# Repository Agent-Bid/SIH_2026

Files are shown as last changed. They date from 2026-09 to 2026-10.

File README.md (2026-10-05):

# Adaptive sonar waveform generator (Tang Nano 9K + ESP32-S3)

An ESP32-S3 takes the water conditions (simulated for now), runs an acoustics model and three
small neural networks, and picks a sonar waveform for every ping, 6 a second: the frequency
band and pulse length, the amplitude, and the modulation (BPSK, LFM or geometric, from how fast
the target moves). It sends the choice over SPI to a Tang Nano 9K FPGA, which generates the
pulses sample by sample at 50.14 MHz for an 8-bit DAC, each with a Hann window.

A PC can stand in for the ESP32 over the Tang Nano's USB UART, and can capture pulses back
from the FPGA (one, or every ping) to check them sample for sample against a Python golden
model.

**Technical documentation** (problem, scientific basis, design, results, limitations, references):
[`docs/Adaptive_Sonar_Technical_Documentation.pdf`](docs/Adaptive_Sonar_Technical_Documentation.pdf)
(also as `.docx`).

**Full project details** (design, packet format, pins, toolchain quirks, status, open items):
[`AGENTS.md`](AGENTS.md). ESP32 firmware and its physics write-up: `MCU /SIH/`.

## Use it

**Demo**: power the ESP32 (it starts pinging on its own), plug the Tang Nano into the PC, then

```
python3 host/demo.py                  # one second: 6 pings on one graph, with the conditions behind each
```

It streams 6 consecutive pings from the FPGA, checks each against the golden model, and plots
them at their real times over one second (grey = baseline, no output), with a table of the
water conditions, the waveform chosen, what the neural networks picked, and the check result
(`sim/out/demo.png`). The ESP32's USB log is used if it is connected; otherwise the conditions
are recomputed from each packet's number (`host/water_sim.py`).

**Other tools**:

```
tn9k load                                                        # build + load the FPGA

python3 host/wavegen.py chirp --fc 325e3 --bw 350e3 --capture    # LFM 150 -> 500 kHz
python3 host/wavegen.py geo   --fc 325e3 --bw 350e3 --capture    # geometric 150 -> 500 kHz
python3 host/wavegen.py bpsk  --fc 300e3 --capture               # Barker-13 at 300 kHz
python3 host/wavegen.py tone  --fc 200e3 --amp 0.75 --capture

python3 host/capture.py --request                                # capture what is playing now
```

- `--capture` asks the board for the next pulse, checks it against the golden model and saves
  a plot in `sim/out/board_capture_<kind>.png` (waveform + spectrogram with the expected sweep).
  Long pulses are captured whole by keeping one sample in 4, 16 or 64.
- `wavegen.py` pulses are 13,000 clocks (259 µs); sweeps go up from `fc - bw/2` to
  `fc + bw/2`; BPSK uses Barker-13 at 1,000 clocks per chip. Other options: `--amp 0..1`,
  `--period <clocks>`, `--port`, `--dry-run`.
- With the ESP32 connected, its packets (one per ping) replace the PC's settings; use
  `capture.py --request` to see what it chose. The ESP32's serial console
  (`python3 host/esp_console.py`): `A` automatic (simulated conditions, the default),
  `W` type the inputs, `M geo|bpsk|lfm|cw|auto` force a modulation, `R 450` the target range.
- The PC talks to the FPGA at 3 Mbaud (`/dev/ttyUSB1`).
- **The DAC output without a scope**: wire pin 40 → 1 kΩ + 100 pF → 10 kΩ + 10 pF → ESP32
  GPIO 1, then `python3 host/dac_view.py --amp 1`. The ESP32 records the filtered voltage while
  the FPGA plays a slow-motion copy of the current ping, and the plot lays it over the FPGA's own
  samples (`sim/out/dac_view.png`). `python3 host/dac_sequence.py` does it for one second of
  pings (6 decisions, each recorded 4× and averaged) on one graph (`sim/out/dac_sequence.png`).
- **The DAC output at full speed**: the filter is now RC (1 kΩ + 100 pF) → OPA340 Sallen-Key
  (10 kΩ, 1 kΩ, 100 pF feedback, 20 pF) on the LASC board's channel 2 (output J6 pin 7). A
  BlackPill (`blackpill/`, flash with `pio run -t upload` in DFU mode) records it at 2.4 MS/s on
  PA1, triggered by pin 41 on PB0. `python3 host/real_speed.py` records 6 consecutive pings, pairs
  each with the FPGA's header for that pulse and plots them unslowed (`sim/out/real_speed.png`).
- **Filter design files**: `hardware/sallen_key_filter/` holds the KiCad schematic of the output
  filter (RC, OPA340 Sallen-Key, RC) and `ac_sweep.cir`, an ngspice AC sweep of it
  (`ngspice ac_sweep.cir`).
- On the board: **S1** steps through three presets (chirp, geometric, BPSK), **S2** captures
  the next pulse (listen with `python3 host/capture.py`).
- **Oscilloscope** (no DAC needed): pin 40 → 1 kΩ → probe point, 100 pF from the probe point
  to GND; trigger on pin 41 (high during each pulse). Without any parts, pin 34 shows a square
  wave at the waveform's frequency (sweep and BPSK phase jumps visible, window not).
- LEDs: 0 BPSK, 1 armed, 2 recording/sending, 3 blinks per good SPI packet, 4 pulse active,
  5 geometric.

## Test in simulation

```
sim/all        # 11 testbenches, ALL PASS
```

`sim/top_tb.v` simulates the whole board: settings over the UART, a pretend ESP32 on SPI
(including a packet with a broken CRC, which must be rejected), and three captures checked
by `host/capture.py`.

## Verified on the board

- 2026-09-29: with the 57-byte packet format, LFM chirp, geometric sweep, BPSK and a tone at
  half amplitude all matched the golden model on all 16,383 captured samples (settings sent
  from the PC over the UART).
- 2026-09-30: the full chain on the boards. The ESP32 (physics + neural network) sends its
  choice over SPI 10 times a second (0 bad packets), and the FPGA plays it bit-exact: an H-S
  chirp at 300 m, then an M-S geometric sweep after `R 600` and `M geo`. Packets are framed by
  the pause after each burst instead of CS (the CS wire does not work on these boards; see
  `AGENTS.md`).
- 2026-09-30: with the oscilloscope outputs added and `scale` split into two clocks (the
  single-clock multiply failed on the chip), ESP32 and PC captures were all bit-exact.
- 2026-09-30: the demo: simulated conditions on the ESP32, 6 pings a second, each a new
  decision; 6 consecutive pings streamed from the FPGA, all bit-exact. This build is in the
  FPGA's flash.
- 2026-10-04: the sigma-delta DAC's filtered output, recorded by the ESP32's ADC in slow motion,
  matches the FPGA's samples (correlation 0.998 at full amplitude; BPSK phase flips visible).

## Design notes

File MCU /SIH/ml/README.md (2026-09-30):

# Waveform-choice model

The ESP32 chooses the waveform with three small neural networks, compiled into the firmware
as `../ml_model.h` (30 KB of weights):

- **profile network** 6 → 48 → 48 → 6 (ReLU): one score for each profile the rule ever picks
  (X-S, H-S, M-S, L-S, L-M, L-L); the highest wins.
- **amplitude network** 12 → 48 → 48 → 1: the 6 inputs plus the chosen profile (one-hot) →
  log(amplitude that just closes the link), plus a small safety margin.
- **modulation network** 16 → 32 → 32 → 3: temperature, salinity, depth, log10(speed + 0.01)
  and the profile (one-hot of 12) → LFM, geometric or BPSK: the Doppler rule in
  `sonar_config.h` section 4c (drift over the pulse ≤ 0.25 cycles → BPSK, ≤ 1 → LFM, else
  geometric). Trained on 200,000 random (conditions, speed, profile) triples.

**Inputs**: temperature (°C), salinity (ppt), depth (m), turbidity (NTU), battery (%), target
range (m); the range is fed as log10(range), and every input is standardised.

**What it learns**: the physics' choice under the detail-vs-energy rule (`sonar_config.h`
section 4b): the finest profile that closes the link using at most 4 × the energy of the
cheapest working profile, or 1 % of the ping's energy budget, whichever is more; and the
amplitude that just closes the link for a profile. The physics still checks every answer:
the profile is kept when it passes the same test (`FLAG_ML_USED`), else replaced
(`FLAG_ML_OVERRIDDEN`); the amplitude is raised if it is too low (`FLAG_ML_AMP_RAISED`).
Set `USE_ML_MODEL 0` in `adaptive_sonar.ino` for physics only.

**Results** (`REPORT.md`): the profile agrees with the physics on about 99.2–99.4 % of
scenarios and 0.5 % of picks are overridden; the amplitude is within 1.8 % (median) of what is
needed and costs 1.6–3.4 % more energy than the minimum; the modulation agrees on 99.7 % (0.2 %
overridden, all at a threshold). XGBoost and a decision tree are
trained on the same data for comparison: the boundaries are smooth curves, which the network
fits with far fewer parameters. The labels come from the physics, so the model reproduces the
physics; it cannot be more accurate than it.

**Retrain** (about 5 minutes on a laptop CPU; no GPU needed):
```
python3 -m venv ml/.venv && ml/.venv/bin/pip install -r ml/requirements.txt
ml/.venv/bin/python ml/train.py          # writes ../ml_model.h, test_vectors.csv, REPORT.md
```
Retrain after any change to `sonar_config.h` that affects the choice (profiles, power,
thresholds, the detail-vs-energy knobs, sensor ranges), then run the firmware tests:
`tools/test_core.cpp` checks that the C networks give the Python models' profile and amplitude
on `test_vectors.csv`, and modulation on `test_vectors_mod.csv`.

**Later, real data**: the model only beats the physics once it learns from measurements.
Log the inputs, the chosen profile and the measured result of each ping (for example the
received level), and train on that instead of the physics labels (`make_set()` in `train.py`).

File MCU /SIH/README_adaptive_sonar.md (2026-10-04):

# Adaptive Sonar Engine — ESP32-S3 + FreeRTOS (100–500 kHz)

This is the final firmware package for the "ESP32 decides, FPGA transmits" design.
This file explains **what the code does in simple words**, **every assumption and correction I made**, and **what the team still has to decide**.

---

## 1. The idea in 60 seconds

The sonar sits in water. The water changes (temperature, salinity, depth, cloudiness) and the battery drains.
Sound at 500 kHz gives very sharp detail but dies quickly in water; sound at 100 kHz travels far but is less sharp.

So the ESP32 does one job for every ping, 6 times a second:

1. **Read 7 inputs**: temperature, salinity, depth, turbidity, battery, target range and the
   target's relative speed. For now they come from a built-in simulation of changing water
   conditions (`water_sim.h`, below); they can also be typed on the serial console or read
   from potentiometers.
2. **Work out the water**: how fast sound travels, how much of it is absorbed at each frequency, how much the murky water and distance weaken it, how noisy the sea is.
3. **Choose a waveform "profile"**: the finest detail that still works with enough signal margin, **unless that costs much more energy** than the cheapest profile that works (the detail-vs-energy rule, section 4).
4. **Set the power just high enough** (so it doesn't waste battery).
5. **Choose the modulation from the motion**: motion shifts every frequency (Doppler), so over
   one pulse the phase drifts fd·T cycles (fd = speed / c × fc). BPSK (Barker-13) while the
   drift is at most 0.25 cycles (cleanest when still), LFM up to 1, geometric sweep beyond
   (tolerates the most motion). Thresholds in `sonar_config.h` section 4c.
6. **Send the choice to the FPGA over SPI.** The FPGA makes the actual pulse.

**The ML model picks the profile, its amplitude and the modulation; physics checks all three.** Three small neural networks (trained on the physics' own decisions, `ml/`) propose them. The physics keeps the profile when it closes the link within the energy allowance (otherwise it chooses itself), raises the amplitude if it is too low, and replaces a modulation that cannot take the Doppler drift. With `USE_ML_MODEL 0` the physics alone decides.

**Simulated water conditions** (`water_sim.h`, the default at power-on; `A` on the serial
console returns to it): a vehicle dives and climbs between 20 and 350 m through a thermocline
(22 → 5 °C) and a halocline, turbidity drifts (plumes, and a muddy layer near the bottom), the
battery drains (and recharges at 15 %), and the sonar tracks three contacts, one per ping in
turn: A near (15–180 m) and lively, B mid-range (250–600 m) and nearly still, C far (450–1000
m) and moving. Ranges and speeds follow smooth random motions, every reading has a little
noise, and mission time runs 10× faster than real time. It is deterministic from its seed.

---

## 2. Files

| File | What it is | Who edits it |
|---|---|---|
| `adaptive_sonar/sonar_config.h` | **Every tunable number** + the profile table | The team (this is the control panel) |
| `adaptive_sonar/sonar_core.h` | Physics, decision logic, FPGA packet. No Arduino code inside, so it can be tested on a PC | Only if the physics changes |
| `adaptive_sonar/adaptive_sonar.ino` | Pins, ADC, FreeRTOS tasks, SPI, serial console | Firmware owner |
| `adaptive_sonar/water_sim.h` | Simulated water conditions (the default input) | Anyone |
| `tools/physics_reference.py` | Python twin of the physics. Reads the **same** `sonar_config.h`; generates ML datasets | ML owner |
| `adaptive_sonar/ml_model.h` | The ML model as C (generated by `ml/train.py`, do not edit) | Regenerate |
| `ml/train.py`, `ml/README.md`, `ml/REPORT.md` | Training: data from the physics twin, model comparison, C export, results | ML owner |
| `tools/test_core.cpp`, `run_tests.sh` | PC tests (see section 9) | Anyone |

Arduino needs the sketch folder name to match the `.ino`, so keep the folder named `adaptive_sonar`.

---

## 3. The 12 profiles

A profile = one ready-made chirp: centre frequency, sweep width (bandwidth), pulse length.
They are ordered **best detail first**; the code takes the first one that works.
(All are linear-FM chirps. Each keeps its full band inside 100–500 kHz.)

| ID | Name | Band | Centre | Bandwidth | Pulse | Range resolution* |
|---|---|---|---|---|---|---|
| 0 / 1 / 2 | X-S / X-M / X-L | 380–500 kHz | 440 kHz | 120 kHz | 1 / 5 / 20 ms | ~0.6 cm |
| 3 / 4 / 5 | H-S / H-M / H-L | 270–330 kHz | 300 kHz | 60 kHz | 1 / 5 / 20 ms | ~1.3 cm |
| 6 / 7 / 8 | M-S / M-M / M-L | 180–220 kHz | 200 kHz | 40 kHz | 1 / 5 / 20 ms | ~1.9 cm |
| 9 / 10 / 11 | L-S / L-M / L-L | 100–140 kHz | 120 kHz | 40 kHz | 1 / 5 / 20 ms | ~1.9 cm |

\*resolution = c / (2 × bandwidth). ID 11 (L-L) is the "best effort" fallback: lowest frequency, longest pulse.

**Why these letters?** Frequency tier (X, H, M, L) controls detail vs reach. Pulse length (S, M, L) controls how much energy goes out per ping.

### The one physics fact that shapes everything
After pulse compression, the signal-to-noise ratio depends on **pulse energy** (power × time), **not on bandwidth**.
So:
- **Bandwidth** buys sharper resolution and costs nothing in SNR.
- **Longer pulse or more power** buys SNR.
- **Higher frequency** buys detail but loses signal faster (absorption grows steeply).

That's why within a frequency tier the code prefers the **shortest** pulse that fits (fast updates, small blind zone) and only goes to longer pulses when the peak-power limit forces it.

A second fact follows from the same physics: **a lower frequency always needs less energy** (water absorbs less, thermal noise is lower). With the detail-vs-energy rule, the longer pulses of the X, H and M tiers are therefore never chosen: they are only needed when the short pulse would exceed the 20 W peak power, which happens at long range, where a lower tier is always much cheaper. In practice the choice is among X-S, H-S, M-S, L-S, L-M and L-L.

---

## 4. How the decision works, step by step

For each profile, best detail first:

1. **Sound speed** from Mackenzie (temperature, salinity, depth).
2. **Absorption** at the profile's centre frequency from Francois-Garrison (temperature, salinity, depth, pH).
3. **Turbidity loss** (extra attenuation from suspended particles).
4. **Spreading loss** = 20·log10(range).
5. **Total transmission loss** = spreading + (absorption + turbidity) × distance.
6. **Noise** = thermal noise + wind noise + receiver noise figure.
7. **Power needed** so that output SNR ≥ 12 dB threshold + 3 dB margin.
8. **Check limits**: needed power ≤ transmitter maximum, and needed energy ≤ what the battery allows per ping, and the chirp fits in the band.
9. **Energy per ping** of every profile that fits: power × pulse length (just enough power, never below 5 % amplitude).
10. **Energy allowance** = the larger of `DETAIL_ENERGY_FACTOR` (4) × the cheapest profile's energy, and `DETAIL_FREE_ENERGY_FRAC` (1 %) × this ping's energy budget. Extra detail is worth up to 4× the minimum energy; energy below 1 % of the budget is too small to be worth saving. The budget shrinks with the battery, so a low battery leans towards saving energy.
11. **Take the finest profile that fits within the allowance.**
12. If nothing fits → last profile at maximum allowed power, flagged `BEST_EFFORT`.

**Anti flip-flop:** to move *up* to a finer profile than the current one, the link needs 2 dB extra margin (which also raises the energy it is charged with). Moving down happens immediately. The same check applies to the ML's pick, so a jittery sensor at a profile boundary cannot make the waveform flip back and forth.

**Tuning:** `DETAIL_ENERGY_FACTOR 1` always takes the cheapest profile (nearly always L-S: the worst detail); a very large value takes the finest profile that works (the older rule).

### Example results (from the Python twin; same numbers as the firmware)

Salinity 35 ppt and depth 50 m in every row.

| Scenario | Old rule (finest that works) | Chosen now | Amplitude | Energy per ping | Old rule's energy | Link |
|---|---|---|---|---|---|---|
| Clear, 10 °C, 300 m, full battery | X-S | **X-S** (440 kHz, 1 ms) | 0.33 | 2.24 mJ | 2.24 mJ | OK |
| Same water, 600 m | H-M | **M-S** (200 kHz, 1 ms) | 0.33 | 2.23 mJ | 68.0 mJ | OK |
| Same water, 600 m, 15 % battery | M-S | **L-S** (120 kHz, 1 ms) | 0.08 | 0.14 mJ | 2.23 mJ | OK |
| Same water, 1000 m | L-S | **L-S** (120 kHz, 1 ms) | 0.84 | 14.2 mJ | 14.2 mJ | OK |
| Warm 25 °C, turbid 80 NTU, 300 m | H-M | **M-S** (200 kHz, 1 ms) | 0.16 | 0.51 mJ | 24.9 mJ | OK |
| Turbid 80 NTU, 15 % battery, 800 m | L-S | **L-S** (120 kHz, 1 ms) | 0.94 | 17.8 mJ | 17.8 mJ | OK |
| Extreme: 2 km, 100 NTU, 10 % battery | L-L | **L-L** (120 kHz, 20 ms) | 0.32 | 40.0 mJ | – | best effort |

Battery only changes the answer when the link is tight (long range), because at short range the energy needed is tiny compared to the budget.

---

## 5. RTOS structure (why the CPU won't stall)

Four tasks, connected by "latest value" queues (length 1, overwrite; plus a short log queue for the PING lines). Nobody waits on anybody, and a slow task can never build a backlog.

```
 core 1                                             core 0
 ┌─────────────┐  latest sample  ┌───────────────┐  latest packet  ┌────────────┐
 │ sensorTask  │ ──────────────▶ │ decisionTask  │ ──────────────▶ │  spiTask   │──▶ FPGA
 │ 50 Hz, prio2│                 │ 6 Hz, prio 3  │                 │50 Hz, prio4│
 │ ADC+filter  │                 │ sim + ML +    │                 └────────────┘
 └─────────────┘                 │ physics       │                 ┌─────────────┐
                                 └──────┬────────┘   telemetry     │ consoleTask │ prio 1
                                        └────────────────────────▶ │ Serial+cmds │
                                                                   └─────────────┘
```

- **sensorTask**: reads 5 pots (16-sample average each) and smooths them, or passes on the typed inputs; publishes the latest. (Not used in automatic mode.)
- **decisionTask**: one decision per ping, 6 a second (exactly on average). In automatic mode it steps the simulation first. Runs the networks and the physics; keeps the anti flip-flop memory per contact. It never touches SPI or Serial, so it can't be blocked by them.
- **spiTask**: highest priority, every 20 ms, sends the latest packet, so a new decision reaches the FPGA well before its next ping.
- **consoleTask**: lowest priority. Serial commands, the PING lines, the reports.
- If sensor data is older than 500 ms, decisions are skipped and the last good packet keeps going.
- The Arduino `loop()` does nothing; all work is in tasks.

**Serial console** (115200; open it with DTR and RTS off, e.g. `host/esp_console.py` in the FPGA project):
- `A`: automatic, simulated conditions (the default). One line per ping:
  `PING seq=… contact=… T=… S=… D=… turb=… bat=… R=… v=… profile=… mod=… amp=… ml_profile=… ml_mod=… ml_amp=… flags=… doppler=…`
- `W`: type the seven inputs one by one (Enter keeps a value, `q` cancels), then a full report: what each network picked and what the physics did with it, the result, and the values sent to the FPGA. `I T S D turb bat R v`: the same on one line, ending with a `DECISION` line for programs.
- `R 450`: target range. `M lfm | geo | bpsk | cw | auto`: force a modulation (`auto` = from the motion). `P`: potentiometers. `L`: status line. `?`: help.
- `C [amp]`: DAC view. Sends the FPGA a slow-motion copy of the current ping (frequencies ÷ up to 100, so the ADC can follow), records the DAC filter's output on GPIO 1 with the ADC (up to 80 kS/s), and prints it (`CAP` header, `D` lines of hex millivolts, `END`) for `host/dac_view.py` in the FPGA project. `S [n] [r]`: the same for the next n decisions (default 6), each recorded r times (default 4), with a `COND` line of conditions before each; for `host/dac_sequence.py`.
- The console writes in small pieces and waits for each to leave: the USB-Serial/JTAG driver loses text that is queued faster than the host reads it, and `Serial.flush()` can discard it.

---

## 6. Packet to the FPGA (57 bytes, little-endian, SPI mode 0)

Version 3. The MCU sends every waveform number **in the FPGA's own units**, so the FPGA never
divides. FTW ("frequency tuning word") = f × 2³² / F_CLK, with F_CLK = 27 MHz × 13/7 =
50.142857 MHz (`FPGA_CLK_HZ` in `sonar_config.h`). The FPGA reads byte 5 and bytes 28–55.

| Bytes | Field | Meaning |
|---|---|---|
| 0 | `sync` | always `0xA5` |
| 1 | `version` | 3 |
| 2–3 | `seq` | counter, increments on each new decision |
| 4 | `profileId` | 0–11 |
| 5 | `modulation` | **FPGA:** 0 = CW, 1 = LFM chirp, 2 = geometric sweep (both up, fc−bw/2 → fc+bw/2), 3 = BPSK Barker-13 at fc |
| 6 | `spreadingFactor` | round(log2(bw × T)) for the sweeps |
| 7 | `flags` | bit0 link OK, bit1 low battery, bit2 input clamped, bit3 ML used, bit4 best effort, bit5 ML overridden, bit6 ML amplitude raised |
| 8–11 | `centerFreqHz` | informational |
| 12–15 | `bandwidthHz` | informational |
| 16–19 | `pulseUs` | informational: pulse duration in µs |
| 20–21 | `amplitude` | informational: 0–65535 = 0–100 % drive |
| 22–23 | `txPowerMilliW` | electrical, informational |
| 24–27 | `propDelayUs` | one-way delay to target range |
| 28–31 | `lenClk` | **FPGA:** pulse length in FPGA clocks (max 2²⁴−1 ≈ 335 ms; BPSK: 13 whole chips) |
| 32–35 | `ftwStart` | **FPGA:** start frequency as an FTW (fc for CW/BPSK, fc − bw/2 for the sweeps) |
| 36–39 | `ftwStep` | **FPGA:** LFM: FTW change per clock × 2¹⁶ (signed). Geometric: (ratio − 1) × 2³², applied every 32 clocks, ratio = (f_end/f_start)^(1/(lenClk/32)). CW/BPSK: 0 |
| 40–43 | `winStep` | **FPGA:** 2³² / lenClk (the Hann window makes one lap per pulse) |
| 44–45 | `ampQ12` | **FPGA:** amplitude, 4096 = 1.0 |
| 46–47 | `code` | **FPGA:** BPSK phase code, chip i = bit i, 1 = flip (Barker-13 = `0x0A60`); else 0 |
| 48–51 | `chipLen` | **FPGA:** BPSK clocks per chip; else 0 |
| 52–55 | `periodClk` | **FPGA:** clocks from one pulse start to the next: `PING_PERIOD_MIN_S` (0.1 s), or pulse + round trip in echo mode |
| 56 | `crc8` | CRC-8 (poly 0x07, init 0) over bytes 0–55 |

The 16 fractional bits of the LFM step matter: a 20 ms, 40 kHz chirp needs a step of 3.416 FTW
per clock, and a whole-number step would sweep 12 % too little. `validateProfiles()` checks at
boot that every profile fits these fields with every modulation.

The FPGA owner must confirm the SPI mode, clock, byte order and whether they want CRC-checked packets (see section 8).

---

## 7. Assumptions and corrections

### 7a. Corrections (things in earlier versions that would not work, now fixed)

| # | What was wrong | What it is now | Why |
|---|---|---|---|
| 1 | **Thorp absorption** was in the earlier code and the team doc | **Francois-Garrison (1982)** | Thorp is a low-frequency fit. Francois-Garrison is published for 200 Hz–1 MHz, so it covers 100–500 kHz, and it uses temperature, salinity, depth and pH, which your doc says absorption should depend on. Thorp ignores temperature, salinity and depth. Example (35 ppt, surface): at 300 kHz Thorp says 67 dB/km, Francois-Garrison says 66 dB/km at 5 °C but 137 dB/km at 30 °C; at 500 kHz Thorp says 112 dB/km, Francois-Garrison says 129 (5 °C) to 199 (30 °C). Using Thorp would badly under-estimate loss in warm water. |
| 2 | Some public Francois-Garrison copies have a **digit typo** (`4.397e-4` instead of `4.937e-4` in the cold-water pure-water term) | Correct `4.937e-4` used | Checked three ways: matches the original paper's form, the two branches of the formula join continuously at 20 °C only with 4.937 (a unit test guards this), and every other term matches an independent public implementation to 6 digits. |
| 3 | Frequency band was 8–30 kHz (my first version) and 90–100 kHz (ML dataset) | **100–500 kHz** | Team requirement. |
| 4 | Simplified sound-speed formula in `predict_profile.py` | Full **Mackenzie** equation | Matches what the dataset was built with; check value 1550.744 m/s at 25 °C, 35 ppt, 1000 m is tested. |
| 5 | Made-up scattering, noise and source-level formulas in my previous code | Published models: thermal noise (Mellen: −15 + 20·log f), wind noise, source level `170.8 + 10·log(P) + DI` | Above ~100 kHz thermal noise dominates. |
| 6 | Earlier SNR ignored pulse compression | Output SNR includes it (`SNR = SL + 10·log T − loss − N0`) | Otherwise the chirp/spreading-factor idea has no effect on the decision. |
| 7 | Single loop with blocking ADC/SPI/Serial | FreeRTOS tasks + queues | Requested; also actually stops the stalls. |
| 8 | ML was the decision maker with nothing checking it | The ML proposes, physics verifies and overrides infeasible picks | Decided with you; the ML is required, physics keeps it safe. |
| 9 | Noise level and range were ML *inputs* but not on your sensor list | Noise is **calculated**; range is a **mission setting** (default 300 m, `R <m>` over Serial) | You only have the 5 sensors. |
| 10 | Boolean-only "feasible" flip-flopping on noisy pots | 2 dB hysteresis for switching up, EMA filtering of the pots | Real sensors are noisy. |
| 11 | XOR checksum, no sequence number | CRC-8 + sequence + version byte | FPGA can detect corruption and stale data. |

### 7b. Assumptions (nobody has confirmed these; all live in `sonar_config.h`)

| Assumption | Default | Confirm with |
|---|---|---|
| Sonar is a **one-way link** (same convention as the ML dataset). Set `ACTIVE_ECHO_MODE 1` for out-and-back echo sonar (doubles the loss, adds target strength −20 dB, and limits pulse length to the round-trip time) | one-way | Whole team |
| Transmitter: 20 W electrical peak, 50 % efficient, omnidirectional (DI = 0 dB) | 20 W / 0.5 / 0 dB | Hardware owner |
| Receiver noise figure | 6 dB | Hardware owner |
| Wind speed for wind noise (no sensor) | 5 m/s | Mission plan |
| pH (only matters below 10 kHz) | 8.0 | none needed |
| **Turbidity loss**: 0.15 dB/km per NTU at 100 kHz, growing linearly with frequency; 1 NTU ≈ 1 mg/L | see left | **Needs calibration.** Anchored to Richards, Heathershaw & Thorne (JASA 1996): about 3 dB extra over 100 m at 100 kHz for 0.2 kg/m³. NTU→concentration and the frequency scaling are site-specific. Set the coefficient to 0 to switch it off. |
| Required output SNR 12 dB (same as ML dataset) + 3 dB link margin for refraction, multipath and filter loss (refraction is not modelled) | 12 + 3 dB | Whole team |
| Spreading: spherical (20·log R) | 20 | Whole team |
| Energy per ping at 100 % battery: 0.4 J, shrinking linearly with SOC down to a 10 % floor | 0.4 J | Hardware owner |
| Absorption is evaluated at the chirp's centre frequency (not averaged across the band) | — | fine for a first version; the 3 dB margin covers most of it |
| Spreading Factor: I interpreted the doc's "SF" as `round(log2(bandwidth × pulse))` (LoRa-style: time-bandwidth = 2^SF) | — | Whoever wrote the doc |
| Pots span exactly the model's valid ranges: 2–30 °C, 25–40 ppt, 0–1000 m, 0–100 NTU, 0–100 % | see config | — |
| ADC full scale ≈ 3100 mV at 11 dB attenuation | 3100 mV | Measure with a multimeter |
| Target range default 300 m (10–2000 m allowed) | 300 m | Mission plan |
| Preference policy: **finest detail within the energy allowance** (4 × the minimum energy, or 1 % of the ping's budget) | `DETAIL_ENERGY_FACTOR` 4, `DETAIL_FREE_ENERGY_FRAC` 0.01 | Whole team (the two numbers set the trade-off) |

---

## 8. What will NOT work until the team decides (blockers)

1. **Transducer coverage.** One transducer rarely covers a 5:1 frequency span (100–500 kHz) with 40–120 kHz sweeps. The firmware assumes it can. If the hardware has separate transducers per band, the profile table and the FPGA switching logic must reflect that. Ask the hardware owner first.
2. **FPGA/DAC speed.** To synthesize up to 500 kHz the DAC/FPGA path must run well above 1 MS/s (Nyquist); realistically 2.5 MS/s or more. Confirm with the FPGA owner.
3. **SPI contract.** Agreed with the FPGA side: SPI mode 0, 2 MHz, packet v3 above, CRC-checked; no ready/ack line. **Verified on the boards (2026-09-30)**: 10 packets/s, none rejected, and the FPGA plays the chosen waveform bit-exact. The FPGA frames packets by the pause after each burst, because the CS wire (GPIO14 → pin 36) does not carry a clean signal on the current boards; the firmware still drives CS as usual.
4. **One-way or echo sonar?** This changes the loss maths (`ACTIVE_ECHO_MODE`). The ML dataset assumes one-way.
5. **Selection policy.** Decided: the detail-vs-energy rule (section 4). Still to tune: the two numbers in `sonar_config.h` section 4b (then retrain the ML).
6. **Turbidity attenuation** needs a real calibration (a turbidity sensor + a known-range acoustic test).
7. **Where the range comes from.** For now it is typed over Serial. If the mission needs it automatic, someone must supply an estimate.

---

## 9. What I verified, and what I could not

Verified on a PC:
- `sonar_core.h` compiles clean with strict warnings.
- Packet v3: the FPGA-unit fields for LFM, geometric and BPSK match values worked out independently in Python (`host/mcu_packet.py` in the FPGA project), every chirp sweeps its full bandwidth within 0.01 %, BPSK always gets 13 whole chips, and the `M` override builds a valid packet.
- The `.ino` type-checks against a mock Arduino/FreeRTOS layer (with `USE_ML_MODEL` 0 and 1). This caught and fixed a real namespace bug.
- 43 automatic checks pass (newest: the Doppler rule: BPSK for every profile when still, never a less tolerant modulation at a higher speed, worked values for X-S, an ML modulation that cannot take the motion is replaced; the C modulation network matches Python on 6,000 vectors; the simulation is repeatable, stays inside the sensor ranges, rotates the contacts, moves them at plausible speeds and exercises 6 profiles and all three modulations; earlier: the detail-vs-energy rule at 600 m and with a low battery; no flip-flop at a profile boundary even with a worst-case ML; the C networks give the Python models' profile and amplitude on 6,000 test vectors; the ML's pick and amplitude are used for the base scenario; a too-low ML amplitude is raised): Mackenzie check value, Francois-Garrison against an independent implementation, continuity at 20 °C, CRC-8 standard value, packet size, band limits, and behaviour sweeps (longer range, lower battery or more turbidity never gives a *finer* profile; NaN and out-of-range inputs are handled; ML hints are accepted only when physics agrees).
- **C++ and the Python twin agree on all 5,000 random scenarios**: 0 profile mismatches, 0 modulation mismatches, max amplitude difference 4e-6, max SNR difference 7e-5 dB.

**Built for the real ESP32-S3** (2026-09-29, arduino-cli, esp32 core 3.3.7, board `esp32s3`, CDCOnBoot=cdc, FlashSize=16M, PSRAM disabled): 337 KB flash (25 %), 22 KB RAM (6 %). One fix was needed: the sketch's own `lerp()` clashed with `std::lerp` from newer C++, so it is now `scaleToRange()`.

**On hardware** (2026-09-30): this build is flashed and runs over the native USB port, or on its own without a USB host. It starts in automatic mode, 6 pings a second, and the FPGA plays every decision bit-exact (checked by streaming 6 consecutive pings back to a PC). The model constants above are engineering defaults, not measurements.

Run the checks yourself: `bash tools/run_tests.sh` (needs `python3` and `g++`).

---

## 10. The ML model

- **What runs** (`adaptive_sonar/ml_model.h`, 30 KB of flash, called by `mlSelect()` and `mlModulation()`):
  - **profile network** 6 → 48 → 48 → 6 (ReLU): one score for each profile the rule ever picks
    (X-S, H-S, M-S, L-S, L-M, L-L); the highest wins.
  - **amplitude network** 12 → 48 → 48 → 1: the 6 inputs plus the chosen profile (one-hot) →
    log(amplitude that just closes the link); a small safety margin (+2.3 %) is added so that it
    is rarely short. The firmware applies the 5 % floor and the power limits.
  - **modulation network** 16 → 32 → 32 → 3: temperature, salinity, depth, log10(speed + 0.01)
    and the profile the physics settled on (one-hot of 12) → LFM, geometric or BPSK.
- **Roles**: the ML always answers. `decide()` keeps its profile when it closes the link within
  the energy allowance, with the anti flip-flop margin (`FLAG_ML_USED`), and otherwise chooses
  itself (`FLAG_ML_OVERRIDDEN`). It uses the ML's amplitude for the ML's profile, raising it to
  what the link needs if it is too low (`FLAG_ML_AMP_RAISED`). `chooseModulation()` keeps the
  ML's modulation when it can take the Doppler drift, else uses the rule's
  (`FLAG_ML_MOD_OVERRIDDEN`).
- **Inputs (6)**: temperature, salinity, depth, turbidity, battery, **range** (as log10).
- **Data**: 300,000 scenarios labelled by `tools/physics_reference.py` (the same
  `sonar_config.h` as the firmware), half with range drawn log-uniformly; tested on
  2 × 20,000 scenarios with other seeds.
- **Results** (`ml/REPORT.md`): the profile agrees with the physics on 99.2 % (uniform range) /
  99.4 % (log range) of scenarios, and 0.5 % of picks are overridden. XGBoost reached 97–99 %
  with ~20,000 tree nodes, a decision tree 94–96 %. The amplitude is within 1.8 % (median) of
  what the link needs; it costs on average 1.6–3.4 % more energy than the minimum, and is raised
  by the physics in 1–2 % of cases. The modulation agrees with the rule on 99.7 % of 20,000
  test cases (0.2 % overridden); every disagreement is within ~1 % of a threshold.
- **Why it is not better than physics**: its labels come from the physics, so it can only copy
  it. It improves on the physics only once it is retrained on measured results (for example the
  received level per ping).
- **Retrain** after any change to `sonar_config.h` that affects the choice (profiles, power,
  thresholds, the detail-vs-energy knobs, sensor ranges):
  `python3 -m venv ml/.venv && ml/.venv/bin/pip install -r ml/requirements.txt && ml/.venv/bin/python ml/train.py`
  (about 5 minutes on a laptop CPU), then run `bash tools/run_tests.sh`.

---

## 11. Wiring and board settings

- Pots (wiper → pin, ends → 3.3 V and GND): temperature GPIO1, salinity GPIO2, depth GPIO3, turbidity GPIO4, battery GPIO5 (all ADC1).
- FPGA SPI: CS GPIO14 → Tang Nano pin 36, MOSI GPIO12 → pin 37, SCK GPIO13 → pin 38, MISO GPIO11 → pin 39 (unused by both sides), plus a GND wire. The Tang Nano pins are in its 3.3 V bank. SPI mode 0, 2 MHz, MSB first, CS low for the whole 57-byte packet.
- Avoid GPIO 26–37 (flash/PSRAM on N16R8), 19/20 (USB), 0/3/45/46 (strapping).
- Arduino IDE: board *ESP32S3 Dev Module*, Flash 16 MB, PSRAM *Disabled* (unused), *USB CDC On Boot: Enabled* if using the native USB port. Serial 115200.

## 12. Sources

- Francois & Garrison (1982), *Sound absorption based on ocean measurements*, JASA 72 (Parts I and II): applies to 200 Hz–1 MHz.
- MB-System `mbabsorption` (independent implementation used as a cross-check).
- Mackenzie (1981), nine-term sound-speed equation.
- Mellen (1952) thermal noise; Wenz/Knudsen-style wind noise fit; thermal noise dominates above ~100 kHz (DOSITS).
- Richards, Heathershaw & Thorne (1996), *The effect of suspended particulate matter on sound attenuation in seawater*, JASA.

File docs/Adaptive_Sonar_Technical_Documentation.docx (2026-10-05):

Adaptive Software-Defined Sonar Transmitter

Complete Technical Documentation

Smart India Hackathon 2026

Problem Statement ID: 26058

Problem Statement Title: Low-Power, Real-Time Adaptive Software-Defined Sonar Transmitter Payload for AUV

PS Category: Hardware

Team Name: CODE RED

Code and design files: github.com/Agent-Bid/SIH_2026

October 2026

Contents

1. Problem and Motivation

2. Scientific Basis

3. System Architecture

4. Hardware: Specifications and Rationale

5. Decision Engine (ESP32-S3 Firmware)

6. Machine Learning Model

7. ESP32 to FPGA Link

8. FPGA Waveform Engine

9. DAC and Analog Output

10. Verification Strategy

11. Results

12. Bill of Materials and Cost

13. Bench Testing Performed

14. Limitations and Honesty Ledger

15. Roadmap

16. How to Build and Run

17. Repository Layout

18. References

# 1. Problem and Motivation

An autonomous underwater vehicle (AUV) uses sonar to see, but the water the sound travels through keeps changing under it. The problem statement asks for a transmitter payload that is low power, real time, adaptive and software defined. This section explains why each of those words matters.

## 1.1 A sonar tuned for one ocean

- The speed of sound in seawater ranges from about 1,450 to 1,550 m/s with temperature, salinity and depth, and an AUV crosses all three on every dive.
- Absorption grows steeply with frequency and with temperature. At the surface in 35 ppt water, 300 kHz loses about 66 dB/km at 5 °C but 137 dB/km at 30 °C, and 500 kHz loses 129 to 199 dB/km over the same temperatures (Francois-Garrison, section 2.2).
- Suspended sediment adds its own loss, and it changes from one plume to the next.
- A conventional sonar is set once on the bench: one frequency, one pulse length, one power. In clear, cold water it wastes power. In warm or murky water it may not reach the target at all.

## 1.2 The resolution versus range dilemma

- Range resolution is c / (2B), where B is the bandwidth of the pulse. A 120 kHz sweep resolves about 0.6 cm; a 40 kHz sweep about 1.9 cm.
- High frequencies give fine detail but die quickly. Low frequencies reach far but blur.
- The right trade-off changes ping by ping with the water and the distance to the target, so no single setting is right for a whole mission.

## 1.3 Battery endurance

- An AUV's mission time is set by its battery. Every joule the sonar spends beyond what the link needs is mission time lost.
- In our simulated mission, a fixed sonar sized for the worst case (120 kHz, 20 ms pulse, full power) spends 178 times the energy per ping of the adaptive design. A cheaper fixed setting (300 kHz, 1 ms) saves energy but loses the target on 29 % of pings (section 11.3).

## 1.4 Motion

- A moving target shifts every frequency by the Doppler effect. Over one pulse the phase drifts by fd × T cycles, where fd is the Doppler shift and T the pulse length.
- Phase-coded pulses (BPSK) give the sharpest result when nothing moves but fall apart quickly with motion. Frequency sweeps tolerate motion much better. The best waveform therefore depends on how fast the target is moving.

## 1.5 The problem as a table

Dimension | Fixed sonar today | Gap | This project's response
Frequency and pulse | Chosen once, on the bench | Wrong for most of the water an AUV meets | Chosen for every ping from a physics model of the water: 12 profiles, 100 to 500 kHz, 1 to 20 ms
Power | Sized for the worst case | Wastes battery on easy pings | Just enough power to close the link plus a 3 dB margin, capped by the battery's state of charge
Modulation | One type | Either blurs, or fails with motion | BPSK, LFM or geometric sweep, chosen from the target's motion
Real time | Not applicable | Decisions must keep up with the pings | 6 decisions a second on the ESP32-S3; the FPGA plays each one within a ping period
Software defined | Fixed analog chirp generator | Cannot change in the field | Every waveform parameter is a number in a 57-byte packet; the FPGA synthesises it digitally
Trust in automation | Not applicable | A neural network alone is a black box | The neural networks propose; the physics checks and can override every pick

# 2. Scientific Basis

Every decision the transmitter makes rests on published underwater acoustics models. This section lists them, why each was chosen, and how we checked our implementation.

## 2.1 Sound speed

- Mackenzie's nine-term equation (1981) gives the speed of sound from temperature, salinity and depth.
- Our implementation is unit-tested against the published check value: 1550.744 m/s at 25 °C, 35 ppt and 1,000 m.

## 2.2 Absorption

- We use Francois and Garrison (1982), which is published for 200 Hz to 1 MHz and so covers our whole 100 to 500 kHz band. It depends on temperature, salinity, depth and pH, which is exactly what changes as the vehicle moves.
- We deliberately did not use Thorp's formula, which is common in simpler designs. It is a low-frequency fit and ignores temperature, salinity and depth, so it badly underestimates loss in warm water at our frequencies.
- Some public copies of Francois-Garrison carry a digit error in the cold-water pure-water term (4.397e-4 instead of 4.937e-4). We use the correct value and guard it with a test: the formula's two temperature branches only join smoothly at 20 °C with the correct digit.
- Every other term matches an independent implementation (MB-System's mbabsorption) to six digits.

## 2.3 Turbidity loss

- Suspended particles add attenuation. We model it as 0.15 dB/km per NTU at 100 kHz, growing in proportion to frequency.
- The figure is anchored to Richards, Heathershaw and Thorne (1996), who measured about 3 dB of extra loss over 100 m at 100 kHz for 0.2 kg/m³ of suspended sediment.
- The conversion from NTU to sediment concentration is site specific, so this coefficient needs calibration in real water (section 14).

## 2.4 Noise

- Above about 100 kHz, the ocean's background noise is dominated by thermal noise, which rises with frequency (Mellen, 1952: -15 + 20 log f dB, f in kHz).
- Wind-driven noise is added for a 5 m/s wind, and the receiver adds a 6 dB noise figure.

## 2.5 The sonar equation and pulse compression

For each candidate waveform the firmware computes:

- Transmission loss: TL = 20 log R + (absorption + turbidity loss) × R
- Source level: SL = 170.8 + 10 log(η × P) + DI, for electrical power P, efficiency η and directivity DI
- Output signal-to-noise ratio after pulse compression: SNR = SL + 10 log T - TL - N0
- Required: 12 dB detection threshold plus a 3 dB margin for refraction, multipath and filter loss

The key consequence is that after pulse compression the SNR depends on the pulse energy (power × time), not on the bandwidth. Three design rules follow from that one fact:

- Bandwidth buys range resolution and costs nothing in SNR.
- A longer pulse or more power buys SNR.
- A lower frequency always needs less energy, because the water absorbs less and the thermal noise is lower.

## 2.6 Waveforms

Waveform | What it is | Strength | Weakness | Used when
CW tone | A single frequency | Simplest | Resolution limited by the pulse length | Test mode
LFM chirp | Frequency rises linearly across the band | Resolution c / 2B; tolerates moderate Doppler | Range and Doppler are coupled | Doppler drift between 0.25 and 1 cycle
Geometric sweep | Frequency multiplied by a constant ratio at each step | Most tolerant of motion in our design | Slightly more complex to generate | Doppler drift above 1 cycle
BPSK, Barker-13 | A tone whose phase flips 180° in a 13-chip pattern | Sharpest: sidelobes 1/13 of the peak (-22.3 dB) | Breaks down quickly with motion | Target nearly still (drift at most 0.25 cycle)

## 2.7 Window

Every pulse is shaped by a Hann window: it starts and ends at zero instead of switching on and off abruptly. This keeps the transmitted spectrum inside the chosen band, which matters both for the transducer and for not spilling energy where it is not wanted (Harris, 1978).

## 2.8 Direct digital synthesis

The FPGA generates waveforms by direct digital synthesis (Tierney, Rader and Gold, 1971). A 32-bit phase accumulator advances by a frequency tuning word every clock, and the top bits of the phase index a sine table. At our 50.142857 MHz clock the frequency resolution is about 0.012 Hz, so any frequency, sweep rate or phase flip in the band can be produced exactly.

## 2.9 Sigma-delta conversion

Our current digital-to-analog stage is a 1-bit sigma-delta modulator: a single pin switches between 0 and 3.3 V at 50 MHz, and the share of time it spends high follows the waveform. A low-pass filter turns that into the analog signal. The order of the modulator sets how strongly its quantisation noise is pushed to high frequencies, where the filter removes it (Schreier and Temes, 2005). We use a second-order modulator (section 9).

# 3. System Architecture

The system is a straight chain from water conditions to analog waveform, with two measurement paths alongside it that let us check every stage on the bench.

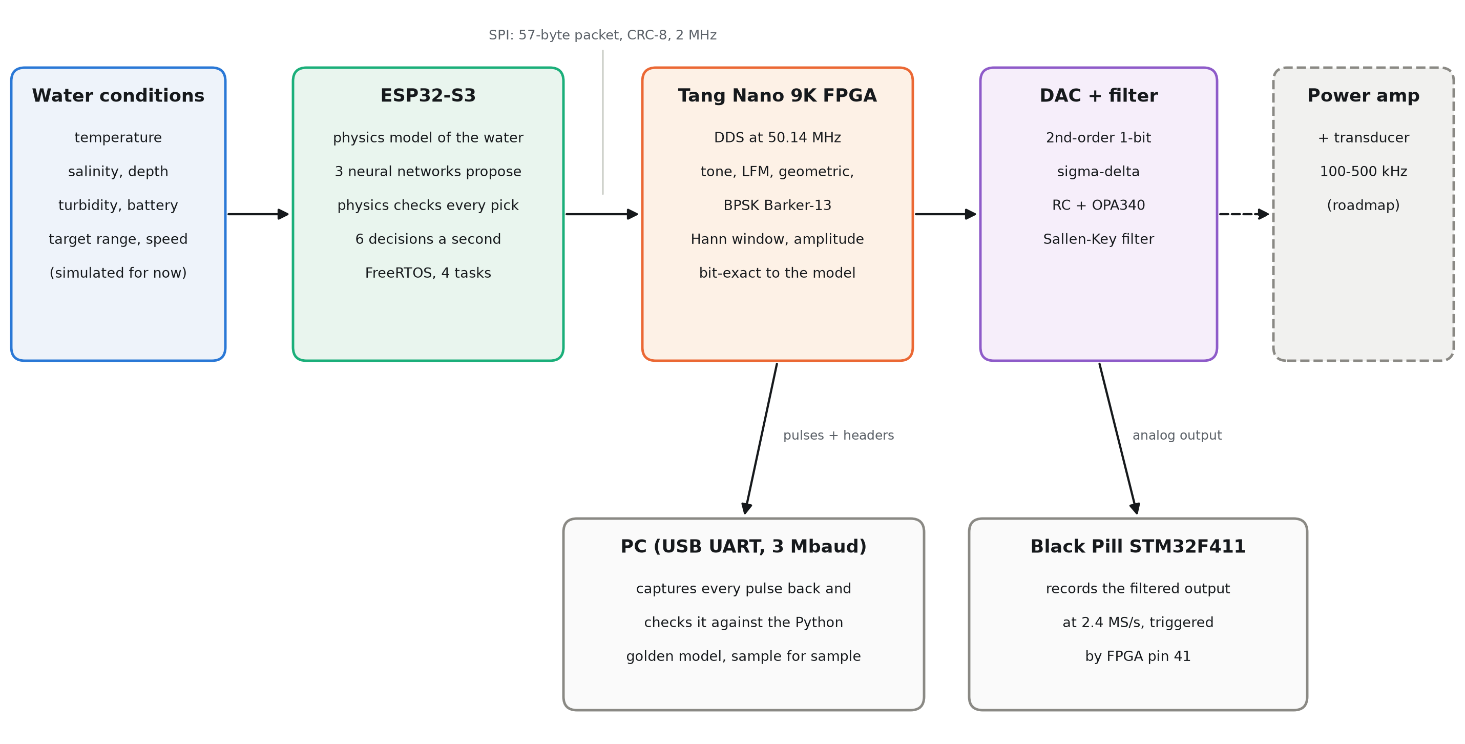
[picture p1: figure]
System architecture. Solid boxes are built and verified; the dashed box is the next stage on the roadmap.

Figure 1. System architecture. Solid boxes are built and verified; the dashed box is the next stage on the roadmap.

Layer | What it owns | Takes input from | Hands off to
1. Inputs | Temperature, salinity, depth, turbidity, battery, target range and speed (simulated for now) | Environment or simulation | Layer 2
2. Decision (ESP32-S3) | Physics model, three neural networks, selection rules, FreeRTOS scheduling | Layer 1 | Layer 3
3. Link | 57-byte packet over SPI with sync byte, version and CRC-8 | Layer 2 | Layer 4
4. Waveform engine (FPGA) | Phase accumulators, sweeps, phase code, window, amplitude: one sample per 20 ns | Layer 3 | Layer 5
5. Conversion | Second-order sigma-delta DAC, RC stage and OPA340 Sallen-Key filter | Layer 4 | Layer 6
6. Transmit (roadmap) | Power amplifier and transducer | Layer 5 | Water

- A packet that fails its checks is never played. The FPGA counts it as bad and keeps playing the last good packet.
- A new packet is only applied between pulses (double buffering), so a pulse is never changed halfway through.
- Each layer can be tested on its own. The PC can stand in for the ESP32, the FPGA can send any pulse back to the PC, and the Black Pill can record the analog output.

# 4. Hardware: Specifications and Rationale

## 4.1 Decision controller: ESP32-S3

Item | Detail
Processor | Dual-core Xtensa LX7 at up to 240 MHz with a single-precision floating-point unit
Why this part | Runs the physics model and three small neural networks well within a ping period; floating point keeps the C model identical to the Python one; native USB and SPI; low cost
Software | Arduino core on FreeRTOS, four tasks (section 5.8)
Interfaces used | SPI to the FPGA (GPIO 12 MOSI, 13 SCK, 14 CS), native USB for the console, GPIO 1 ADC for the slow-motion DAC view

## 4.2 Waveform engine: Sipeed Tang Nano 9K (Gowin GW1NR-9 FPGA)

Item | Detail
Resources | 8,640 LUT4, 6,480 flip-flops, 26 block RAMs
Clock | 27 MHz crystal, PLL to 50.142857 MHz (27 × 13 / 7)
Our use | 49 % of LUTs, 50 % of flip-flops, 18 of 26 block RAMs; timing closes at 65.7 MHz against the 50.14 MHz needed
Why an FPGA | Every sample comes out on an exact 20 ns grid and matches a reference model bit for bit. A microcontroller cannot generate 500 kHz sweeps, phase flips and windows with that precision while also doing everything else.
Toolchain | Fully open source: yosys, nextpnr-himbaechel, Apycula, openFPGALoader

## 4.3 Digital-to-analog stage

- In use now: a second-order 1-bit sigma-delta on FPGA pin 40, followed by an RC stage (1 kΩ, 100 pF) and an OPA340 Sallen-Key low-pass filter (section 9).
- OPA340: single supply 2.7 to 5.5 V, rail-to-rail input and output, 5.5 MHz gain-bandwidth, 6 V/µs slew rate. It runs from the same 3.3 V as the logic, and its slew rate comfortably covers our largest signal (about 3 V/µs at 500 kHz).
- Why not the DAC0808 board we started with: it needs a negative supply (-5 to -15 V), and the TL084 op-amps on that board (3 MHz gain-bandwidth) are too slow for a 650 kHz fifth-order Butterworth filter. The board is shelved, not abandoned.
- For the final transmitter: the FPGA already drives an 8-bit parallel DAC bus (pins 25 to 34) with a sample clock (pin 35), ready for a single-supply high-speed DAC of the DAC908 or AD9708 class.

## 4.4 Measurement: Black Pill (STM32F411CE)

- Its 12-bit ADC samples the filter output at 2.4 MS/s: the chip runs at 72 MHz so that the ADC clock is exactly 36 MHz, with 15 clocks per sample.
- DMA fills a 40,000-sample ring buffer (16.6 ms). A rising edge on FPGA pin 41 marks each pulse's start, so every recording is aligned to its pulse.
- This gives the real 100 to 500 kHz waveform on a laptop, with no slow-motion trick and no oscilloscope needed.

## 4.5 FPGA pin map

Signal | FPGA pin | Connected to
Clock | 52 | 27 MHz oscillator
SPI MOSI / SCK / CS | 37 / 38 / 36 | ESP32 GPIO 12 / 13 / 14
UART TX / RX | 17 / 18 | On-board USB UART to the PC (3 Mbaud)
DAC data [7:0] | 25, 26, 27, 28, 29, 30, 33, 34 | Parallel DAC (offset binary), for the final transmitter
DAC clock | 35 | Parallel DAC sample clock (inverted system clock)
Sigma-delta output | 40 | RC stage, then the Sallen-Key filter
Pulse trigger | 41 | High for the whole pulse: Black Pill PB0 and the oscilloscope trigger
Buttons | 3 / 4 | S1 steps through test presets; S2 captures the next pulse
LEDs | 10, 11, 13, 14, 15, 16 | BPSK, capture armed, recording, good packet, pulse active, geometric

## 4.6 Power

- Each board runs from its own USB supply, with all grounds joined. Supply rails are never tied together.
- The FPGA is powered first (or together with the ESP32), so the ESP32 never drives signals into an unpowered FPGA.
- The op-amp runs from 3.3 V and draws well under 1 mA.

# 5. Decision Engine (ESP32-S3 Firmware)

For every ping, six times a second, the ESP32 reads its inputs, works out what the water is doing to sound at each frequency, picks the waveform, sets the power and builds the packet for the FPGA.

## 5.1 Inputs

Input | Range | Source today
Temperature | 2 to 30 °C | Simulated
Salinity | 25 to 40 ppt | Simulated
Depth | 0 to 1,000 m | Simulated
Turbidity | 0 to 100 NTU | Simulated
Battery | 0 to 100 % | Simulated
Target range | 10 to 2,000 m | Simulated per contact
Relative speed | 0 to 10 m/s | Simulated per contact

The inputs can also be typed on the serial console or read from potentiometers, which is useful for testing one condition at a time.

## 5.2 Simulated water conditions

Until real sensors are fitted, a built-in simulation drives the system through a realistic mission:

- The vehicle dives and climbs between 20 and 350 m every 20 mission-minutes, through a thermocline (22 °C down to 5 °C) and a halocline (34.4 to 35.2 ppt).
- Turbidity is a background level plus drifting sediment plumes and a muddy layer near the bottom.
- The battery drains and recharges at 15 %.
- Three contacts are pinged in turn: A near (15 to 180 m) and lively, B mid-range (250 to 600 m) and nearly still, C far (450 to 1,000 m) and moving. Ranges and speeds follow smooth random motions.
- Every reading carries a little sensor noise, and mission time runs 10 times faster than real time so a demo covers a lot of ocean.
- It is deterministic from its seed. A Python copy reproduces it to within 0.001 over 20,000 pings, so the PC can work out the conditions behind any packet from its sequence number.

## 5.3 Waveform profiles

Profiles | Band | Centre | Bandwidth | Pulse lengths | Resolution
X-S / X-M / X-L | 380 to 500 kHz | 440 kHz | 120 kHz | 1 / 5 / 20 ms | about 0.6 cm
H-S / H-M / H-L | 270 to 330 kHz | 300 kHz | 60 kHz | 1 / 5 / 20 ms | about 1.3 cm
M-S / M-M / M-L | 180 to 220 kHz | 200 kHz | 40 kHz | 1 / 5 / 20 ms | about 1.9 cm
L-S / L-M / L-L | 100 to 140 kHz | 120 kHz | 40 kHz | 1 / 5 / 20 ms | about 1.9 cm

The letter gives the frequency tier (detail against reach); S, M and L give the pulse length (energy per ping). L-L is the best-effort fallback: the lowest frequency with the longest pulse.

## 5.4 How a decision is made

1. Sound speed from Mackenzie.
2. For each profile: absorption at its centre frequency (Francois-Garrison), turbidity loss and spreading loss give the transmission loss.
3. Noise: thermal plus wind plus the receiver's noise figure.
4. The power needed for an output SNR of at least 12 dB plus the 3 dB margin.
5. Check the limits: the power must be within the transmitter's 20 W peak, the energy within what the battery allows for this ping, and the sweep within the band.
6. The energy each workable profile would spend: just enough power, never below 5 % amplitude.
7. Apply the detail-versus-energy rule (5.5) to pick the profile.
8. Choose the modulation from the target's motion (5.6).
9. Convert everything into the FPGA's own units and build the packet.

## 5.5 The detail-versus-energy rule

- Take the finest profile whose energy is at most the larger of: 4 times the energy of the cheapest profile that works, or 1 % of this ping's energy budget.
- In words: extra detail is worth up to four times the minimum energy, and energy below 1 % of the budget is too small to be worth saving.
- The budget shrinks with the battery (0.4 J per ping at full charge, falling linearly to a 10 % floor), so a low battery leans towards saving energy.
- Because a lower frequency always needs less energy, the rule in practice only ever picks X-S, H-S, M-S, L-S, L-M or L-L.
- If no profile closes the link, the transmitter sends L-L at the maximum allowed power and flags the ping as best effort.

## 5.6 Modulation from motion

- Doppler shift: fd = v / c × fc, doubled in echo mode. The drift over one pulse is fd × T cycles.
- BPSK while the drift is at most 0.25 cycle (cleanest when still); LFM up to 1 cycle; geometric sweep beyond that.
- Example: at 440 kHz with a 1 ms pulse, a target moving at 0.5 m/s drifts about 0.15 cycle, so BPSK is kept; at 2 m/s it drifts about 0.6 cycle, so LFM is used.

## 5.7 Stability: no flip-flopping

To move up to a finer profile than the one a contact is currently using, the link must close with 2 dB of extra margin. Moving down happens immediately. The memory is kept per contact, so a noisy sensor at a profile boundary cannot make the waveform jump back and forth from ping to ping.

## 5.8 Real-time structure

Task | Rate | Priority | Job
spiTask | 50 Hz | 4 (highest) | Sends the latest packet to the FPGA, so a new decision always arrives well before the next ping
decisionTask | 6 Hz | 3 | Steps the simulation, runs the networks and the physics, publishes the packet. Never touches SPI or the console, so it can never be blocked by them
sensorTask | 50 Hz | 2 | Reads and smooths the potentiometers or passes on typed inputs (idle in automatic mode)
consoleTask | On demand | 1 (lowest) | Serial commands, the per-ping log and reports

Tasks share data through length-one queues that always hold the latest value, so a slow task can never build up a backlog. If sensor data is older than 500 ms, decisions pause and the last good packet keeps going.

## 5.9 Serial console

Command | What it does
A | Automatic: simulated conditions (the default at power-on), one log line per ping
I T S D turb bat R v | Type all seven inputs on one line and hold that condition; prints the full decision report
W | Asks for the inputs one by one
M lfm | geo | bpsk | cw | auto | Force a modulation, or return to choosing it from the motion
R <metres> | Set the target range
C [amp] and S [n] [r] | Record the DAC output in slow motion with the ESP32's ADC (section 9.4)

# 6. Machine Learning Model

## 6.1 Role: the network proposes, the physics verifies

- Three small neural networks run on the ESP32 for every ping and propose the profile, the amplitude and the modulation.
- The physics keeps the proposed profile only if it closes the link within the energy allowance; otherwise it chooses itself.
- It raises the proposed amplitude if it is too low for the link, and caps it at what the battery allows.
- It replaces a proposed modulation that cannot tolerate the target's Doppler drift.
- Every override is recorded in the packet's flags, so it is visible in the logs and in every capture.

## 6.2 Networks

Network | Shape | Inputs | Output
Profile | 6 → 48 → 48 → 6 (ReLU) | Temperature, salinity, depth, turbidity, battery, log10(range), standardised | One score per profile the rule can pick
Amplitude | 12 → 48 → 48 → 1 | The same six inputs plus the chosen profile (one-hot) | log(amplitude that just closes the link), plus a 2.3 % safety margin
Modulation | 16 → 32 → 32 → 3 | Temperature, salinity, depth, log10(speed + 0.01) plus the profile (one-hot of 12) | LFM, geometric or BPSK

Together they hold 7,706 weights (30 KB), generated as a C header straight from training. The C code gives the same answers as the Python models on all 6,000 test vectors of each network.

## 6.3 Training data

- 300,000 scenarios labelled by a Python copy of the firmware's physics, half of them with the range drawn evenly on a log scale so short and long ranges are both well covered.
- Inputs rounded to 32-bit floats, as on the ESP32.
- The modulation network trains on 200,000 random combinations of conditions, speed and profile.
- Tested on two separate sets of 20,000 scenarios generated with different seeds.

## 6.4 Results

Model | Size | Same profile as the physics | Picks overridden
Decision tree (depth 14) | 10,707 nodes | 93.8 % / 96.0 % | 4.9 %
XGBoost (depth 5, 60 rounds) | 19,864 nodes | 97.1 % / 98.1 % | 2.2 %
XGBoost with product features | 20,906 nodes | 98.0 % / 98.7 % | 1.6 %
Neural network (used) | 2,982 weights | 99.2 % / 99.4 % | 0.5 %

Agreement is given for the evenly spread range set and the log-spread range set. Further results:

- Amplitude: within 1.8 % (median) of what the link needs, costing on average 1.6 to 3.4 % more energy than the minimum; the physics raises it in 1 to 2 % of cases.
- Modulation: agrees with the rule on 99.7 % of 20,000 test cases, with 0.2 % overridden. Every disagreement lies within about 1 % of a threshold.
- Per-class recall for the profile network is 98 to 100 % for every profile it can choose.

## 6.5 Why small neural networks

The decision boundaries are smooth curves in the input space. A small network fits them with a few thousand weights, while tree models need around 20,000 nodes and still agree less often. The network also fits comfortably in the ESP32's flash and runs in well under a millisecond.

## 6.6 Limits and the path to beating the physics

The labels come from the physics model, so today the network can only copy it. It becomes better than the physics only when it is retrained on measured results: logging the conditions, the choice and the received level of each ping, then training on what actually worked (section 15).

# 7. ESP32 to FPGA Link

## 7.1 SPI

- SPI mode 0, 2 MHz, most significant bit first. The ESP32 sends the latest packet as one 57-byte burst (228 µs) every 20 ms.
- Packets are framed by the pause after each burst: a frame ends when the clock has been quiet for 100 µs. On our boards the chip-select wire only ever carried noise, while the clock and data lines were clean, so we designed the receiver not to depend on it. Chip select can be switched back on with one parameter.
- Any byte count other than 57, a wrong sync byte or version, or a bad CRC means the packet is rejected and counted.

## 7.2 Packet format (version 3, 57 bytes, little-endian)

Bytes | Field | Meaning
0 | sync | 0xA5
1 | version | 3
2 to 3 | seq | Increments with every new decision
4 | profileId | 0 to 11
5 | modulation | Used by the FPGA: 0 tone, 1 LFM, 2 geometric, 3 BPSK
6 | spreadingFactor | round(log2(bandwidth × pulse length)) for sweeps
7 | flags | Link OK, low battery, input clamped, ML profile used, best effort, ML profile overridden, ML amplitude raised, ML modulation overridden
8 to 27 | telemetry | Centre frequency, bandwidth, pulse length, amplitude, power, propagation delay
28 to 31 | lenClk | Pulse length in FPGA clocks
32 to 35 | ftwStart | Start frequency as a tuning word
36 to 39 | ftwStep | Sweep step (LFM: per clock × 2^16; geometric: ratio per 32 clocks)
40 to 43 | winStep | 2^32 / lenClk, so the window makes exactly one lap per pulse
44 to 45 | ampQ12 | Amplitude, 4096 = 1.0
46 to 47 | code | BPSK phase code (Barker-13 = 0x0A60)
48 to 51 | chipLen | BPSK clocks per chip
52 to 55 | periodClk | Clocks between pulse starts (1/6 s at 6 pings a second)
56 | crc8 | CRC-8, polynomial 0x07, over bytes 0 to 55

The ESP32 sends every waveform parameter already in the FPGA's own units, so the FPGA never has to divide. The 16 fractional bits of the LFM step matter: a 20 ms, 40 kHz chirp needs a step of 3.416 tuning-word units per clock, and rounding it to a whole number would sweep 12 % too little.

## 7.3 The PC as a second source

The PC can send the same packet over the board's USB UART (3 Mbaud), which lets us test any waveform without the ESP32. Over the same link the PC can ask the FPGA to capture one pulse, or every pulse (stream mode), and send it back for checking.

# 8. FPGA Waveform Engine

## 8.1 Clock and units

- System clock 50,142,857 Hz from the PLL.
- Frequency tuning word: f × 2^32 / F_CLK. One hertz is about 85.65 units.
- Phase is a 32-bit fraction of a cycle; the 1,024-entry sine table is indexed by its top 10 bits.
- Amplitudes and window values are fixed point, with 4096 meaning 1.0.

## 8.2 Signal chain, one sample per clock

1. A pulse timer fires a start every period. The pulse controller holds the engine active for exactly the pulse length.
2. The sweep unit produces the instantaneous frequency (constant, linear or geometric).
3. The phase accumulator adds it every clock. For BPSK, the phase code adds half a cycle (180°) on the chips marked in the code.
4. The sine table turns the phase into a 12-bit sample.
5. A second phase accumulator steps through the Hann window, exactly one lap per pulse.
6. Two multipliers apply the window and then the amplitude. Each takes two clocks: the factor is split into two parts whose products are registered, then added.
7. The result drives the sigma-delta DAC, the parallel DAC bus and the capture unit.

## 8.3 Sweeps

- LFM: a 48-bit register holds the tuning word with 16 fraction bits; every clock it adds the signed step. Long, narrow chirps therefore sweep exactly the bandwidth asked for.
- Geometric: every 32 clocks the register is multiplied by (1 + step / 2^32). The multiply is done by shift-and-add, one bit per clock, so no wide multiplier is needed.

## 8.4 BPSK

A chip counter advances every chip length; the phase flips by 180° whenever the current chip's bit in the code is 1. Barker-13 (+ + + + + - - + + - + - +) is stored as 0x0A60, and the pulse is always exactly 13 whole chips.

## 8.5 Settings path

- A packet from the ESP32 or the PC is checked one byte per clock: sync, version and CRC.
- A good packet goes into a pending register. It is copied into the active settings only while no pulse is playing, so a pulse is never changed halfway through.
- The packet's sequence number, profile and flags travel with its settings, and a 16-bit counter numbers every pulse, so every capture states exactly which decision and which pulse it holds.

## 8.6 Capture and streaming

- The capture unit records 16,384 samples of the next pulse into block RAM, keeping one sample in 2^n where n is the smallest value that fits the whole pulse (one in 4 for 1 ms pulses, one in 64 for 20 ms).
- It then sends a 43-byte header (all the pulse's settings, packet and pulse numbers, good and bad packet counts) and the samples over the UART at 3 Mbaud, in about 0.11 s.
- In stream mode it re-arms after every capture, so all 6 pings of every second reach the PC.

## 8.7 Limits

Quantity | Limit
Pulse length | 24 bits: up to about 335 ms
Period between pulses | 32 bits of clocks: up to about 85 s
LFM sweep rate | Up to about 19 GHz/s (the sonar profiles need at most 0.12 GHz/s)
Phase code | Up to 16 chips (Barker-13 used)
Frequency | Numerically up to about 20 MHz; the sonar band is 100 to 500 kHz

# 9. DAC and Analog Output

## 9.1 Second-order sigma-delta modulator

- Two integrators run every clock: i1 += x - fb, then i2 += i1 - fb, where x is the sample and fb is ±2048 for the previous output bit. The output bit is 1 when i2 is zero or positive.
- The noise transfer is (1 - z^-1)^2, so the quantisation noise is pushed far above 100 to 500 kHz, where the filter removes it.
- The input is limited to ±95 % of full scale. In simulation this keeps the integrators bounded (below 10,000 and 50,000), whereas an input held at full scale made the second integrator grow without limit.
- The original first-order version is still available through a parameter, so the two can be compared on the same hardware.
- Both versions are checked bit for bit against Python models of the modulator in simulation.

## 9.2 Filter

- Stage 1, RC: 1 kΩ and 100 pF (corner about 1.6 MHz) removes the fastest switching before the op-amp sees it.
- Stage 2, Sallen-Key low-pass: 10 kΩ and 1 kΩ in series into the OPA340's + input, 20 pF from that input to ground, and 100 pF from the junction of the two resistors to the op-amp output. The op-amp is wired as a unity-gain follower. Cut-off about 1.1 MHz, Q about 0.64, nearly flat across the band.
- Stage 3, RC: 10 kΩ and 10 pF after the op-amp, for the oscilloscope and the ESP32's ADC.
- The op-amp output also drives the Black Pill's ADC directly, acting as the buffer a fast ADC needs.

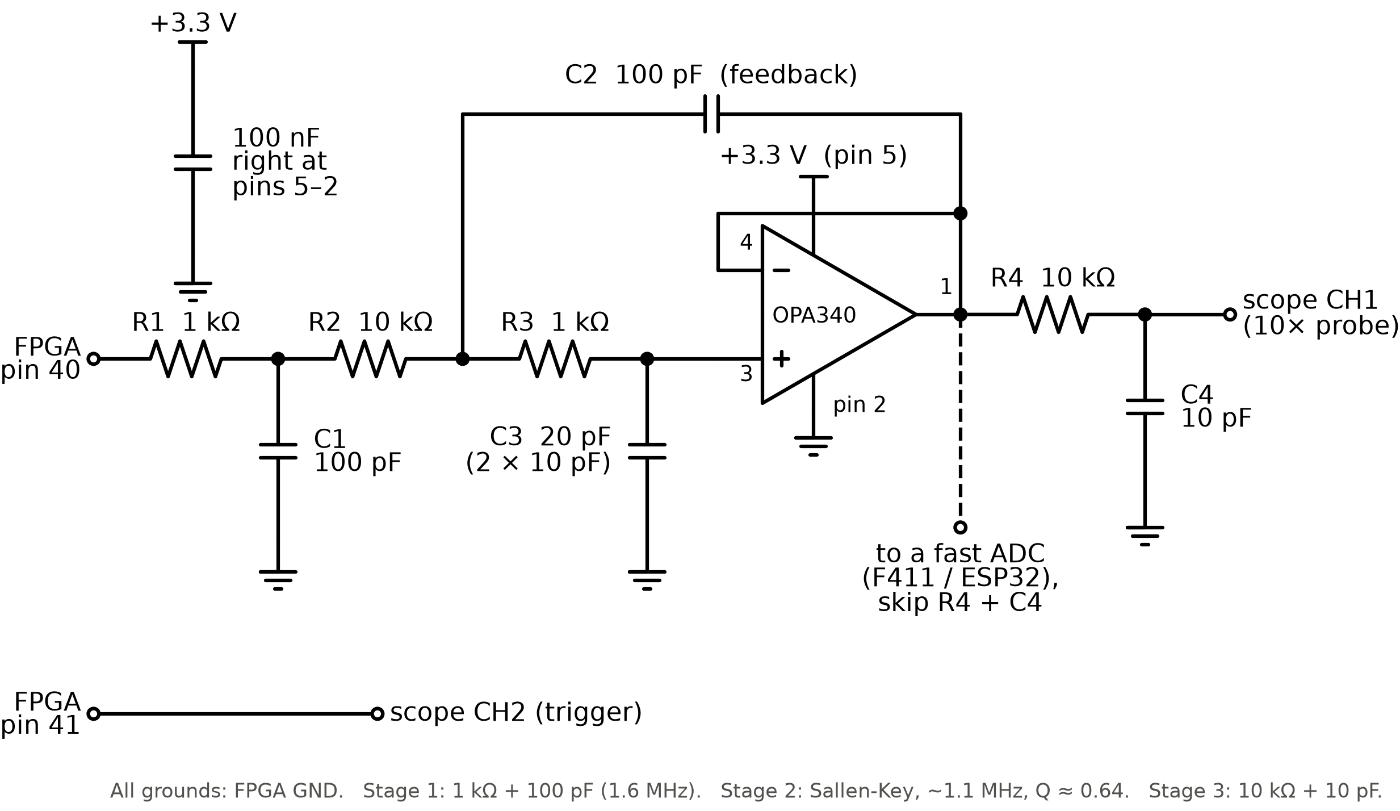
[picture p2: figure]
The analog output stage: RC stage, OPA340 Sallen-Key low-pass filter and output RC stage.

Figure 2. The analog output stage: RC stage, OPA340 Sallen-Key low-pass filter and output RC stage.

## 9.3 Measured at full speed

We recorded the same three fixed pings with the Black Pill, first with the first-order modulator and then with the second-order one. The difference is the measured output minus the FPGA's samples, after removing each recording's DC offset and fitting its gain.

Ping | Match, first order | Match, second order | Difference, first order | Difference, second order
L-S BPSK, 120 kHz, amp 0.56 | 0.997 | 0.998 | 28.0 mV rms | 21.8 mV rms
H-S geometric, 270 to 330 kHz, amp 0.22 | 0.995 | 0.996 | 15.6 mV rms | 12.8 mV rms
X-S BPSK, 440 kHz, amp 0.05 | 0.868 | 0.926 | 17.2 mV rms | 12.5 mV rms

- "Match" is the correlation between the measured trace and the FPGA's own samples (1 is perfect).
- The second-order modulator lowers the remaining error by 20 to 30 % and lifts the hardest case, a faint 440 kHz ping, from 0.87 to 0.93.
- About 9 to 10 mV rms of what remains is the Black Pill's own noise floor, measured on the quiet baseline between pulses.
- The output height is 1.00 of the intended value at 120 kHz, 0.95 at 300 kHz and 0.86 at 440 kHz. Lengthening the ADC's sampling time five-fold did not change these figures, so the loss is real and in the analog path. Adding about 10 pF of stray wiring capacitance at the op-amp's input to the filter model reproduces it almost exactly (0.99, 0.94 and 0.84).

## 9.4 Slow-motion recording with the ESP32

Before the Black Pill, we verified the DAC with the ESP32's own ADC, which manages only about 80,000 samples a second. The ESP32 sends the FPGA a copy of the current ping with every frequency divided by up to 100 and the pulse made that much longer, records it, and the PC lines the recording up with the FPGA's samples. At full amplitude this gave a correlation of 0.998, with the BPSK phase flips clearly visible. It shows the waveform's shape, but not the filter's behaviour at the real frequencies, which is why the full-speed recording above was added.

# 10. Verification Strategy

## 10.1 The golden model is the specification

A Python model reproduces the FPGA's datapath bit for bit, including every pipeline delay and every rounding step. Every change to the hardware is mirrored in the model, every simulation is compared against it, and every capture from the real board must match it on every sample.

## 10.2 Simulation testbenches

Testbench | What it checks
phase_acc, pulse_ctrl, phase_code | Module behaviour, self-checking
capture | Header and samples at three decimation settings, and two streamed captures after one arm
dds | Tone against the golden model, plus the spectrum's peak
pulse_dds | Windowed pulses against the golden model; the window narrows the spectrum
chirp | LFM up and down, bit-exact, and the measured sweep
geo | Geometric sweep, bit-exact, and exactly two octaves measured
bpsk | Barker-13, bit-exact, and the code read back from the samples
sigma_delta | First- and second-order bit streams bit-exact against their models; the filtered output follows the waveform
top | The whole board: a chirp over the UART, an SPI packet with a broken CRC (rejected) and a good geometric packet, BPSK over the UART, and three captures checked end to end

All 11 testbenches pass.

## 10.3 Firmware tests

- 43 automatic checks on the PC: the Mackenzie check value, Francois-Garrison against an independent implementation, CRC-8 against its standard check value, packet size and band limits, the Doppler rule, the anti flip-flop margin, the detail-versus-energy rule, and the simulation's repeatability.
- Behaviour sweeps: a longer range, a lower battery or more turbidity never produces a finer profile; invalid inputs are handled.
- The C++ firmware and its Python copy agree on 5,000 random scenarios: no profile or modulation mismatches, amplitudes within 4e-6 and SNR within 7e-5 dB.
- The C neural networks match the Python models on all test vectors.

## 10.4 On-board tools

Tool | What it shows
demo.py | Streams 6 consecutive pings from the FPGA, checks each against the golden model and plots one second of the running system with the conditions behind each ping
wavegen.py, capture.py | Set any waveform from the PC, capture it back, check it and plot its waveform and spectrogram
real_speed.py | Records 6 consecutive pings after the DAC at 2.4 MS/s with the Black Pill and plots them over the FPGA's samples
dac_view.py, dac_sequence.py | The slow-motion DAC recordings from the ESP32's ADC
energy_compare.py | The adaptive design's energy against fixed sonars over a full battery cycle

# 11. Results

## 11.1 The whole system, bit-exact

With the ESP32 running the simulated mission, six consecutive pings are streamed back from the FPGA. Each is a new decision for a different contact, and every one matches the golden model on every sample.

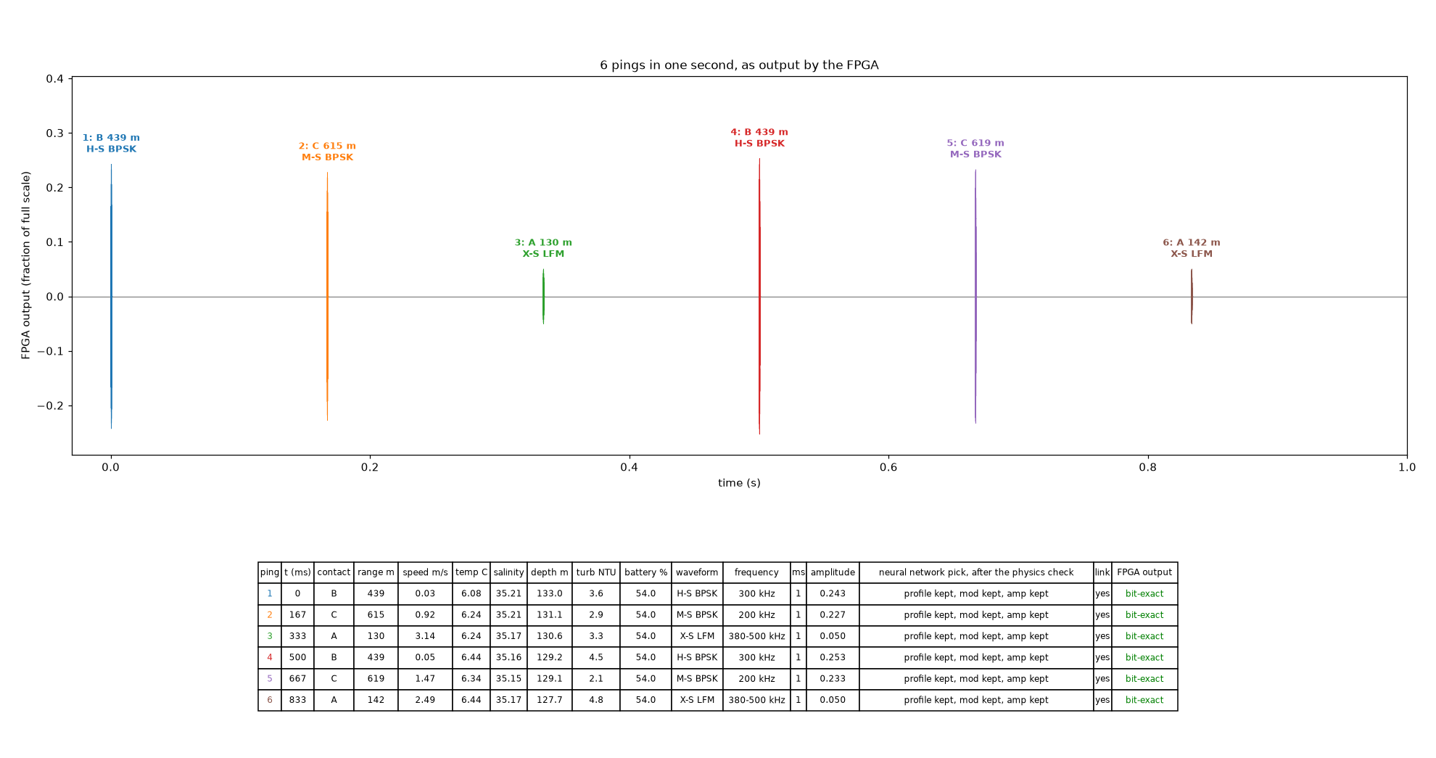
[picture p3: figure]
One second of the running system: six pings chosen by the ESP32 for three contacts, as output by the FPGA. Every ping is bit-exact against the golden model.

Figure 3. One second of the running system: six pings chosen by the ESP32 for three contacts, as output by the FPGA. Every ping is bit-exact against the golden model.

## 11.2 Waveforms captured on the board

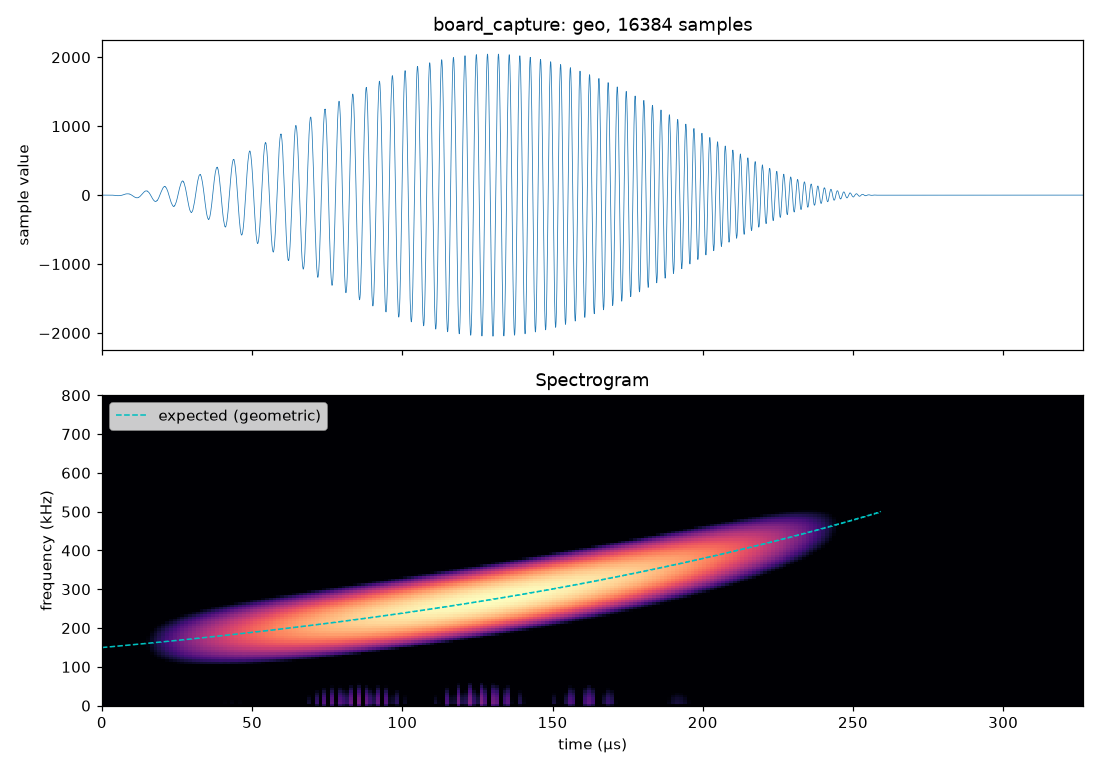
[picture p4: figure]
A geometric sweep from 150 to 500 kHz captured from the FPGA: the Hann-windowed waveform (top) and its spectrogram, with the expected sweep as a dashed line (bottom).

Figure 4. A geometric sweep from 150 to 500 kHz captured from the FPGA: the Hann-windowed waveform (top) and its spectrogram, with the expected sweep as a dashed line (bottom).

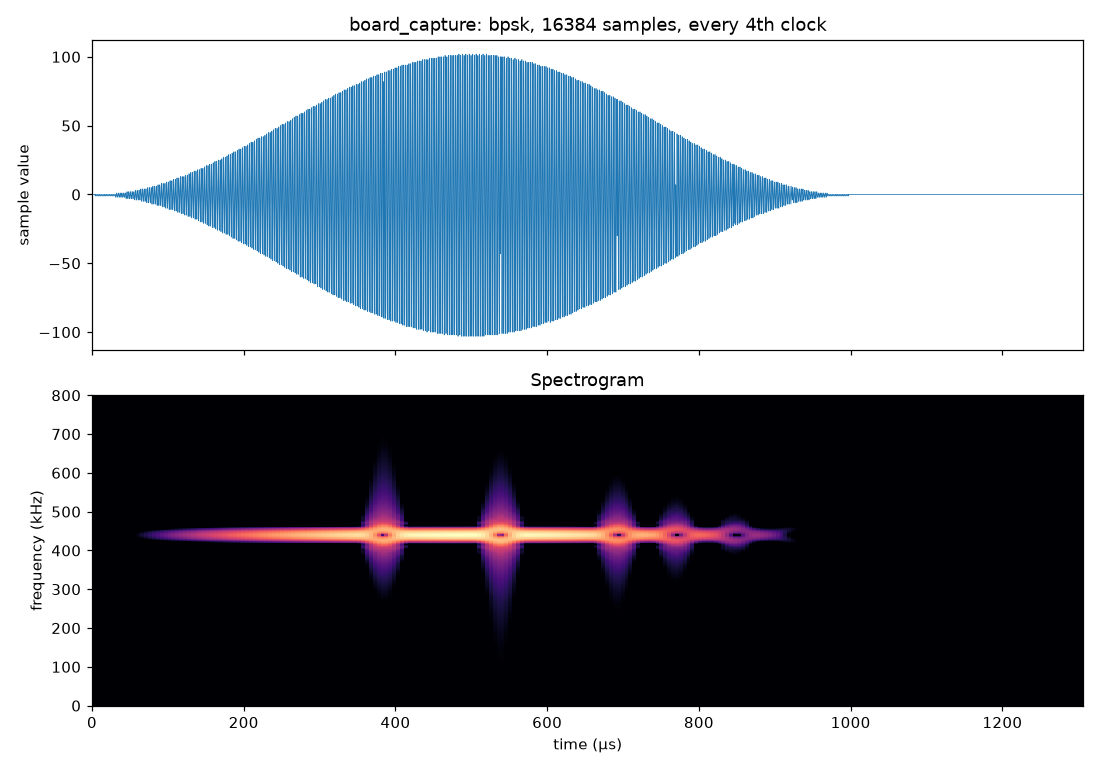
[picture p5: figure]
A Barker-13 BPSK pulse at 300 kHz captured from the FPGA.

Figure 5. A Barker-13 BPSK pulse at 300 kHz captured from the FPGA.

## 11.3 Energy

Over one full battery cycle of the simulated mission (10,200 pings, about 28 minutes at 6 pings a second):

Transmitter | Average energy per ping | Link closes on
Adaptive (this project) | 1.29 mJ | 100 % of pings
Fixed L-L (120 kHz, 20 ms) at full allowed power | 230 mJ (178 × more) | 100 % of pings
Fixed H-S (300 kHz, 1 ms) at full power | 20 mJ (15 × more) | 70.7 % of pings

- The adaptive transmitter chose X-S on 33.3 % of pings, M-S on 24.0 %, L-S on 22.5 %, H-S on 18.9 %, L-M on 1.2 % and L-L on 0.2 %.
- A fixed sonar must either be sized for the worst case and waste energy on every easy ping, or be economical and lose the target when conditions get hard. The adaptive design does neither.
- These figures use the physics rule without the neural networks, which agree with it on more than 99 % of choices.

## 11.4 The analog output at full speed

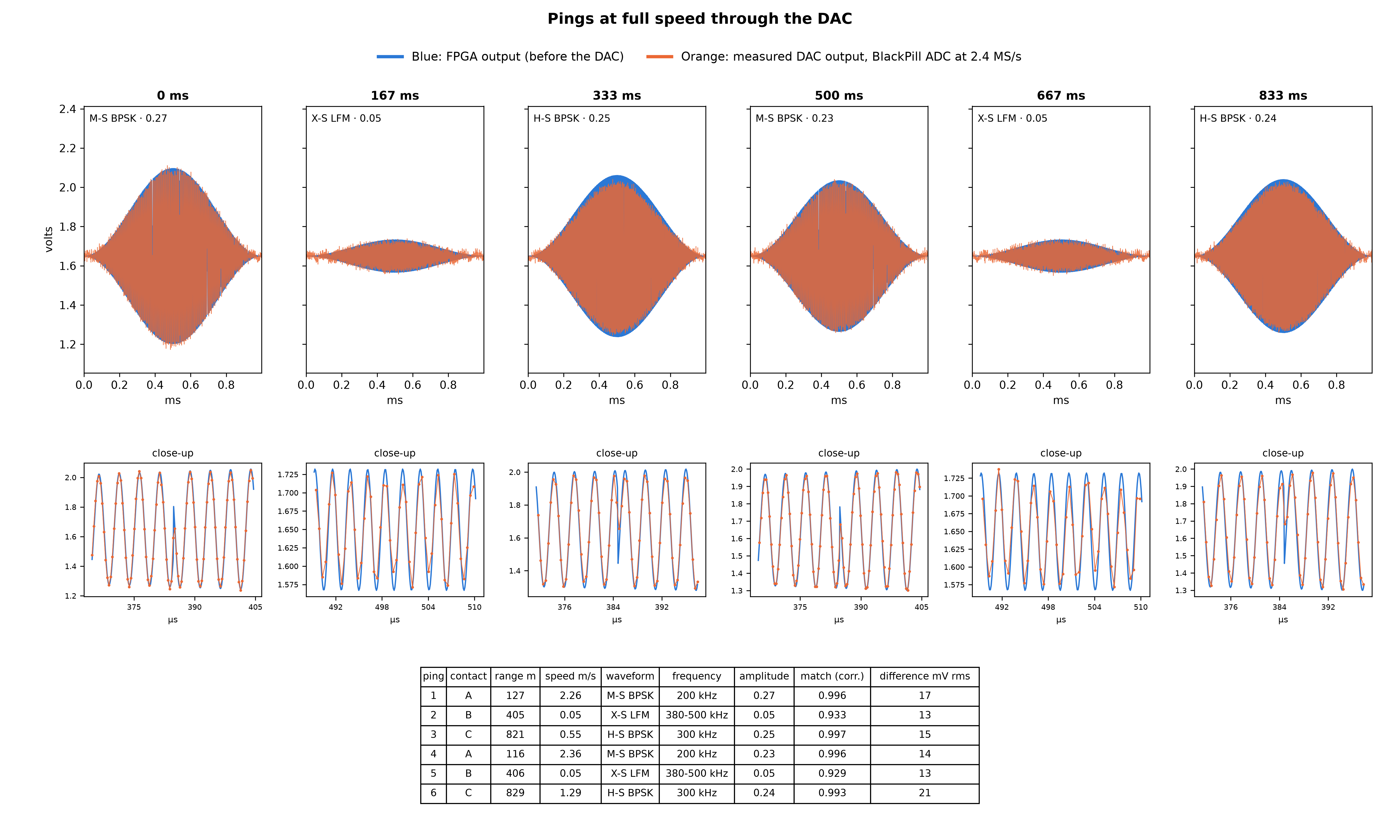
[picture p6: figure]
Six consecutive pings after the second-order sigma-delta and the Sallen-Key filter, recorded at 2.4 MS/s by the Black Pill (orange), over the FPGA's own samples (blue). Close-ups show individual carrier cycles and the BPSK phase flips.

Figure 6. Six consecutive pings after the second-order sigma-delta and the Sallen-Key filter, recorded at 2.4 MS/s by the Black Pill (orange), over the FPGA's own samples (blue). Close-ups show individual carrier cycles and the BPSK phase flips.

# 12. Bill of Materials and Cost

Prices are indicative ranges from Indian hobby electronics suppliers and vary with supplier and quantity. Confirm before ordering.

Subsystem | Component | Approx. cost (India) | Notes
Decision controller | ESP32-S3 development board | About Rs. 700 to 1,200 | Any ESP32-S3 board with native USB
Waveform engine | Sipeed Tang Nano 9K | About Rs. 1,800 to 2,500 | Gowin GW1NR-9 FPGA, on-board USB JTAG and UART
Analog output | OPA340 op-amp | About Rs. 150 to 300 | Single supply, rail-to-rail
Analog output | Resistors, capacitors, perfboard, wires | Under Rs. 150 | 1 kΩ, 10 kΩ, 10 pF, 100 pF, 100 nF
Test equipment | Black Pill STM32F411CE | About Rs. 450 to 700 | Used for measurement, not part of the payload
Prototype total | | About Rs. 3,000 to 4,800 | Excluding test equipment, power amplifier and transducer

For the final payload, the parallel DAC, power amplifier and transducer still have to be selected (section 15). The FPGA and the decision firmware do not change when they are added.

# 13. Bench Testing Performed

## 13.1 Timeline

Date | Test | Result
29 Sep 2026 | FPGA on the board, waveforms set from the PC | LFM, geometric, BPSK and a half-amplitude tone all matched the golden model on all 16,383 captured samples
30 Sep 2026 | ESP32 to FPGA over SPI | 10 packets a second, none rejected; the FPGA played every decision bit-exact
30 Sep 2026 | Timing fix on the chip | A single-clock multiply gave occasional wrong samples on the real chip although timing analysis passed; splitting it into two registered steps made 5 of 5 captures bit-exact
30 Sep 2026 | Whole system demo | Simulated conditions, 6 pings a second, 6 consecutive pings streamed and all bit-exact; the PC's copy of the simulation matched the ESP32's log
4 Oct 2026 | DAC in slow motion (ESP32 ADC) | Correlation 0.998 at full amplitude; BPSK phase flips visible
4 Oct 2026 | Six pings through the DAC | Matches of 0.92 to 0.999 after averaging 4 recordings each
5 Oct 2026 | Sallen-Key filter and full-speed recording | Real-speed pulses on the laptop at 2.4 MS/s, matches up to 0.995
5 Oct 2026 | Second-order sigma-delta | 20 to 30 % less error on the same fixed pings; the faint 440 kHz ping improved from 0.87 to 0.93
5 Oct 2026 | Source of the high-frequency loss | Not the ADC (unchanged with 5 times longer sampling); matches about 10 pF of stray capacitance

## 13.2 Test status

Test | Status
Waveform engine bit-exact on the board | Complete
ESP32 decisions sent and played without errors | Complete
Whole system, 6 pings a second, streamed and checked | Complete
DAC output recorded at full speed | Complete
Second-order sigma-delta compared with first order | Complete
Oscilloscope confirmation of the filter output | Outstanding at the time of writing
Real water sensors in place of the simulation | Outstanding
Power amplifier and transducer | Outstanding
In-water test of the link | Outstanding

# 14. Limitations and Honesty Ledger

Each part of the system is listed with the strongest evidence we actually have for it, to avoid claiming more than we have shown.

Part | Evidence | What it does not show yet
Waveform engine (FPGA) | Verified on hardware: every sample matches the golden model | Nothing outstanding for the digital output
ESP32 decisions and link | Verified on hardware: 6 a second, no bad packets, every decision played bit-exact | Behaviour with real sensors
Physics model | Published models, cross-checked against independent implementations and tested in software | Validation in real water
Turbidity loss | Anchored to one published measurement | Needs calibration with a turbidity sensor and a known-range test
Doppler thresholds | Engineering rules of thumb (0.25 and 1 cycle) | Need confirming against measured echoes
Neural networks | Agree with the physics on more than 99 % of tested scenarios | Cannot outperform the physics until trained on measured data
Analog output | Measured at full speed with a 2.4 MS/s ADC | Independent oscilloscope check; the final parallel DAC
Water conditions | Deterministic, realistic simulation | Real sensors
Power stage | Not built | Everything

## 14.1 Known limitations

- The model treats the link as one-way (the same convention as the training data). Echo mode, with twice the loss and a target strength, is implemented but not yet the default; the team must decide which applies to the mission.
- One transducer rarely covers a 5:1 frequency span such as 100 to 500 kHz. The firmware assumes it can; separate transducers per band would need the profile table and the FPGA's output switching to reflect that.
- Absorption is evaluated at each profile's centre frequency rather than averaged across the band; the 3 dB margin covers most of the difference.
- The analog output loses about 14 % of its height at 440 kHz because of stray capacitance in the perfboard wiring. A proper PCB, or a smaller 10 pF capacitor in place of 20 pF, would flatten the response.
- The ESP32 and the FPGA each keep their own 6 Hz ping clock, so about once every few hours a ping may repeat or skip a decision. A trigger line from the FPGA would synchronise them.
- The chip-select wire between the boards carries only noise. The link works without it, but the cause was not found.
- The target's range and speed are simulated. In service they must come from the sonar's own echoes or another sensor such as a DVL.

## 14.2 Scope

This prototype covers the transmitter's intelligence and waveform generation, from water conditions to an analog signal, verified on the bench. The power amplifier, transducer, receiver and in-water testing are outside what has been built so far and are the next stages of the roadmap.

# 15. Roadmap

1. Oscilloscope confirmation of the filter output against the Black Pill's measurements.
2. Parallel DAC: a single-supply high-speed DAC (DAC908 or AD9708 class) on the existing 8-bit bus and sample clock, replacing the 1-bit stage for transmission.
3. Power amplifier and transducer: a wideband transducer, or one per band, with output switching in the FPGA.
4. Real sensors for temperature, salinity, depth and turbidity in place of the simulation.
5. Calibration in water: turbidity loss, absorption and the Doppler thresholds against a known-range target.
6. Closing the loop for the neural networks: log the received level of each ping with its conditions and choice, and retrain on what actually worked. This is the step at which the networks can do better than the physics model.
7. Range and speed from echoes: estimate them from the sonar's own returns instead of a mission setting.
8. Synchronisation: a trigger line from the FPGA so that decisions and pings share one clock.
9. Tuning with the team: the detail-versus-energy settings (4 times the minimum energy, 1 % of the budget) and one-way versus echo operation, followed by retraining.

# 16. How to Build and Run

Everything runs from the root of the repository. The FPGA flow is fully open source.

Step | Command
Run all FPGA simulations | sim/all
Build and load the FPGA (volatile) | tn9k load
Build and write the FPGA's flash | tn9k flash
Build the ESP32 firmware | arduino-cli compile with board esp32s3 (CDCOnBoot=cdc, 16 MB flash); see AGENTS.md
Flash the Black Pill (in DFU mode) | pio run -t upload in blackpill/
One second of the running system | python3 host/demo.py
Pings at full speed after the DAC | python3 host/real_speed.py
Energy comparison | python3 host/energy_compare.py
Set and capture a waveform from the PC | python3 host/wavegen.py geo --fc 325e3 --bw 350e3 --capture
Firmware tests on the PC | bash tools/run_tests.sh (inside the firmware package)
Retrain the neural networks | python ml/train.py (about 5 minutes on a laptop CPU)

The ESP32 starts in automatic mode at power-on and needs no PC. Only the FPGA has to be connected for the demo. The full details, including toolchain versions and hardware quirks, are in AGENTS.md in the repository.

# 17. Repository Layout

Path | Contents
top.v and the other .v files | The FPGA design: packet input and checking, waveform engine, capture, sigma-delta DAC
sim/ | Testbenches and the scripts that run them
host/ | Golden model, packet tools, demo, capture, DAC recording and energy scripts
MCU /SIH/ | ESP32-S3 firmware: physics, decision rules, simulation, neural networks, tests and the firmware write-up
MCU /SIH/ml/ | Training code, report and test vectors for the neural networks
blackpill/ | Firmware for the 2.4 MS/s recorder
AGENTS.md | The full engineering guide: design, packet, pins, toolchain quirks, status and open items

# 18. References

1. Mackenzie, K. V. (1981). Nine-term equation for sound speed in the oceans. Journal of the Acoustical Society of America, 70(3), 807-812.
2. Francois, R. E., and Garrison, G. R. (1982). Sound absorption based on ocean measurements. Part I: Pure water and magnesium sulfate contributions. JASA, 72(3), 896-907.
3. Francois, R. E., and Garrison, G. R. (1982). Sound absorption based on ocean measurements. Part II: Boric acid contribution and equation for total absorption. JASA, 72(6), 1879-1890.
4. Mellen, R. H. (1952). The thermal-noise limit in the detection of underwater acoustic signals. JASA, 24(5), 478-480.
5. Wenz, G. M. (1962). Acoustic ambient noise in the ocean: spectra and sources. JASA, 34(12), 1936-1956.
6. Richards, S. D., Heathershaw, A. D., and Thorne, P. D. (1996). The effect of suspended particulate matter on sound attenuation in seawater. JASA, 100(3), 1447-1450.
7. Urick, R. J. (1983). Principles of Underwater Sound, 3rd edition. McGraw-Hill.
8. Barker, R. H. (1953). Group synchronizing of binary digital systems. In Communication Theory, W. Jackson (ed.), Butterworths, 273-287.
9. Harris, F. J. (1978). On the use of windows for harmonic analysis with the discrete Fourier transform. Proceedings of the IEEE, 66(1), 51-83.
10. Tierney, J., Rader, C. M., and Gold, B. (1971). A digital frequency synthesizer. IEEE Transactions on Audio and Electroacoustics, 19(1), 48-57.
11. Schreier, R., and Temes, G. C. (2005). Understanding Delta-Sigma Data Converters. Wiley-IEEE Press.
12. Sallen, R. P., and Key, E. L. (1955). A practical method of designing RC active filters. IRE Transactions on Circuit Theory, 2(1), 74-85.
13. MB-System, mbabsorption: an independent implementation of the Francois-Garrison absorption model, used as a cross-check.
14. Texas Instruments. OPA340 single-supply, rail-to-rail operational amplifier, datasheet.

Adaptive Software-Defined Sonar Transmitter | Team CODE RED | SIH 2026, PS 26058

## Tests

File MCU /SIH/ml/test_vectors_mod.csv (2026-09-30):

# temperature | salinity | depth | speed | profile | modulation | score margin (float32)
4.52951574 | 39.2595024 | 149.971054 | 3.33985162 | 11 | 2 | 71.6548
7.14554071 | 26.3276386 | 915.982056 | 3.97724843 | 7 | 2 | 51.7837
17.1362743 | 30.8185177 | 405.739746 | 0.193496734 | 8 | 1 | 40.1727
23.6430702 | 25.6085091 | 257.246399 | 0.345841467 | 0 | 3 | 86.543
17.9697533 | 37.5685997 | 52.48629 | 0.320561796 | 11 | 1 | 39.9267
13.990056 | 28.3996296 | 205.257492 | 0.0979219675 | 0 | 3 | 137.849
4.9995966 | 39.0067863 | 310.524536 | 0.0406660847 | 7 | 3 | 132.811
6.90499306 | 27.4614525 | 309.073303 | 0.0424695052 | 10 | 3 | 155.774
5.64524937 | 35.4682922 | 415.113861 | 0.642741084 | 1 | 1 | 5.06164
13.1830425 | 34.8636017 | 78.8608322 | 0 | 11 | 3 | 156.199
21.5675659 | 29.4737625 | 269.84552 | 0 | 6 | 3 | 229.015
24.130497 | 32.4516411 | 68.5730133 | 0.116390832 | 4 | 3 | 76.6867
8.28813744 | 33.3871956 | 472.393433 | 0.0676666871 | 3 | 3 | 150.483
24.3723907 | 35.9038696 | 355.285828 | 1.30233204 | 8 | 2 | 57.9279
27.2471466 | 25.0583229 | 355.017578 | 0.292911321 | 7 | 3 | 31.4021
16.8629761 | 39.2378502 | 405.574585 | 0.0422493555 | 3 | 3 | 162.299
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

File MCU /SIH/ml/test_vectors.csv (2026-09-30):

# temperature | salinity | depth | turbidity | battery | range | profile | score margin | amplitude (float32)
5.93032074 | 25.3542423 | 998.630676 | 18.4253654 | 12.059206 | 1306.32825 | 9 | 9.40213 | 0.6387341
26.9074268 | 28.4761219 | 959.485046 | 31.9451847 | 60.1142273 | 1864.85437 | 11 | 37.9074 | 1
27.8677769 | 35.6217232 | 48.4403343 | 88.1367416 | 58.9555817 | 628.255615 | 9 | 9.51294 | 0.5416133
25.7946377 | 33.7423592 | 937.988892 | 77.3952179 | 96.1192017 | 1136.96265 | 11 | 23.9377 | 1
19.1450901 | 28.8761635 | 956.717041 | 31.2472382 | 78.1109619 | 1909.72229 | 11 | 41.9239 | 1
5.98225498 | 37.3783913 | 667.500732 | 18.5028362 | 4.91251087 | 1068.31494 | 9 | 5.01485 | 0.7949899
27.9022655 | 32.5941963 | 517.311646 | 40.9442139 | 66.0999832 | 1833.76245 | 11 | 46.2416 | 1
12.4657974 | 33.7389069 | 297.318512 | 59.5634499 | 54.3120499 | 872.608948 | 10 | 2.91556 | 0.5166751
16.7907391 | 26.3216419 | 996.484131 | 35.5699692 | 43.1759338 | 811.578308 | 9 | 18.1814 | 0.2463049
28.6603909 | 32.6799011 | 400.659058 | 9.65658474 | 89.5500412 | 351.07785 | 6 | 11.8782 | 0.12618
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

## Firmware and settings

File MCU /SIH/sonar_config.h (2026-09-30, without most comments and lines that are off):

#pragma once
#include <stdint.h>
#define BAND_MIN_HZ            100000.0f   // team requirement: 100 kHz ...
#define BAND_MAX_HZ            500000.0f   // ... to 500 kHz (whole chirp must fit inside)
#define TX_ELEC_POWER_MAX_W    20.0f       // [ASSUMPTION] peak electrical power into transducer
#define TX_EFFICIENCY          0.50f       // [ASSUMPTION] electrical -> acoustic efficiency
#define TX_DIRECTIVITY_DB      0.0f        // [ASSUMPTION] 0 = omnidirectional (conservative)
#define RX_NOISE_FIGURE_DB     6.0f        // [ASSUMPTION] receiver noise figure added to ocean noise
#define FPGA_CLK_HZ            (27.0e6 * 13.0 / 7.0)   // 27 MHz x PLL 13/7 = 50.142857 MHz
#define FPGA_STEP_FRAC_BITS    16                      // ftwStepQ16 = FTW change per clock x 2^16
#define FPGA_LEN_MAX_CLK       16777215UL              // 24-bit pulse length and chip length (~335 ms)
#define BARKER13_CODE          0x0A60
#define BARKER13_CHIPS         13
#define PING_RATE_HZ           6                       // pings (and decisions) per second
#define PING_PERIOD_MIN_S      0.16666667f             // 1 / PING_RATE_HZ
#define ASSUMED_PH             8.0f        // only matters < 10 kHz, harmless at 100-500 kHz
#define ASSUMED_WIND_SPEED_MS  5.0f        // [ASSUMPTION] for wind noise (small vs thermal above ~200 kHz)
#define SPREADING_COEFF        20.0f       // 20 = spherical spreading, 15 = "practical" spreading
#define TURB_ATTEN_DB_KM_PER_NTU_AT_100K  0.15f
#define TURB_FREQ_EXPONENT                1.0f   // loss grows ~ f^n
#define ACTIVE_ECHO_MODE       0
#define TARGET_STRENGTH_DB     (-20.0f)    // used only if ACTIVE_ECHO_MODE = 1
#define DETECTION_THRESHOLD_DB 12.0f       // required output SNR (same 12 dB as ML dataset)
#define LINK_MARGIN_DB         3.0f        // extra safety for refraction, multipath, filter loss...
#define SWITCH_UP_HYSTERESIS_DB 2.0f       // need this much EXTRA margin before moving to a
#define AMP_MIN_FRAC           0.05f       // never drive below 5 % amplitude
#define DETAIL_ENERGY_FACTOR     4.0f       // [ASSUMPTION] pay up to 4x the minimum energy for more detail
#define DETAIL_FREE_ENERGY_FRAC  0.01f      // [ASSUMPTION] up to 1 % of the ping's budget always counts as affordable
#define SPEED_MIN_MS             0.0f       // relative speed (magnitude), m/s
#define SPEED_MAX_MS             10.0f
#define DEFAULT_SPEED_MS         0.0f
#define DOPPLER_BPSK_MAX_CYCLES  0.25f      // [ASSUMPTION] BPSK while fd x T <= this
#define DOPPLER_LFM_MAX_CYCLES   1.0f       // [ASSUMPTION] LFM while fd x T <= this, geometric beyond
#define ENERGY_PER_PING_MAX_J  0.4f        // [ASSUMPTION] electrical energy allowed per ping at 100 % SOC
#define SOC_FLOOR_PCT          10.0f       // budget stops shrinking below this SOC (never fully silent)
#define LOW_BATTERY_PCT        20.0f       // sets the LOW_BATTERY flag in the packet
#define DEFAULT_TARGET_RANGE_M 300
#define MIN_TARGET_RANGE_M     10
#define MAX_TARGET_RANGE_M     2000        // can be changed at runtime from Serial: "R 450"
#define TEMP_MIN_C             2.0f
#define TEMP_MAX_C             30.0f
#define SALINITY_MIN_PPT       25.0f
#define SALINITY_MAX_PPT       40.0f
#define DEPTH_MIN_M            0.0f
#define DEPTH_MAX_M            1000.0f
#define TURBIDITY_MIN_NTU      0.0f
#define TURBIDITY_MAX_NTU      100.0f
#define BATTERY_MIN_PCT        0.0f
#define BATTERY_MAX_PCT        100.0f
enum Modulation : uint8_t { MOD_CW = 0, MOD_LFM_CHIRP = 1, MOD_GEOMETRIC = 2, MOD_BPSK = 3 };
struct WaveProfile {
  const char* name;
  float       fcHz;      // centre frequency
  float       bwHz;      // chirp bandwidth (sweep width)
  float       pulseS;    // pulse duration in seconds
  Modulation  mod;
};
static const WaveProfile PROFILES[] = {
  { "X-S",  440000.0f, 120000.0f, 0.001f, MOD_LFM_CHIRP },   //  0  380-500 kHz, 1 ms
  { "X-M",  440000.0f, 120000.0f, 0.005f, MOD_LFM_CHIRP },   //  1
  { "X-L",  440000.0f, 120000.0f, 0.020f, MOD_LFM_CHIRP },   //  2
  { "H-S",  300000.0f,  60000.0f, 0.001f, MOD_LFM_CHIRP },   //  3  270-330 kHz
  { "H-M",  300000.0f,  60000.0f, 0.005f, MOD_LFM_CHIRP },   //  4
  { "H-L",  300000.0f,  60000.0f, 0.020f, MOD_LFM_CHIRP },   //  5
  { "M-S",  200000.0f,  40000.0f, 0.001f, MOD_LFM_CHIRP },   //  6  180-220 kHz
  { "M-M",  200000.0f,  40000.0f, 0.005f, MOD_LFM_CHIRP },   //  7
  { "M-L",  200000.0f,  40000.0f, 0.020f, MOD_LFM_CHIRP },   //  8
  { "L-S",  120000.0f,  40000.0f, 0.001f, MOD_LFM_CHIRP },   //  9  100-140 kHz
  { "L-M",  120000.0f,  40000.0f, 0.005f, MOD_LFM_CHIRP },   // 10
  { "L-L",  120000.0f,  40000.0f, 0.020f, MOD_LFM_CHIRP },   // 11  <- best-effort fallback
};
#define NUM_PROFILES ((int)(sizeof(PROFILES) / sizeof(PROFILES[0])))

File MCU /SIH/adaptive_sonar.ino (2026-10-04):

/*
  ============================================================================
  Adaptive Sonar Parameter Engine  --  ESP32-S3 (N16R8) + FreeRTOS
  ============================================================================
  Takes the conditions (by default from a simulation of changing water conditions,
  water_sim.h; or typed on the serial console, or 5 potentiometers), runs the physics
  model and the neural networks, picks a waveform for every ping (profile 100-500 kHz,
  amplitude, and LFM / geometric / BPSK from the motion), 6 pings a second, and sends
  it to the FPGA over SPI.

  Files:  sonar_config.h  = every tunable number + the profile table
          sonar_core.h    = physics, decision logic, FPGA packet (PC-testable)
          this file       = hardware, FreeRTOS tasks, SPI, serial
  See README_adaptive_sonar.md for the plain-language walkthrough.

  Arduino IDE board settings (ESP32S3 Dev Module):
    Flash size 16MB | PSRAM "Disabled" (not needed) | USB CDC On Boot: Enabled
    (if you use the native USB port for Serial)

  Serial commands (115200 baud; host/esp_console.py in the FPGA project is a terminal that
  does not reset the board):
      A          -> automatic: simulated water conditions (the default); prints one PING
                    line per ping
      C [amp]    -> DAC view: records the DAC filter output on GPIO 1 during a slow-motion copy
                    of the current ping, optionally at another amplitude 0..1 (host/dac_view.py
                    in the FPGA project plots it)
      S [n] [r]  -> the same for the next n decisions (default 6 = one second), each recorded
                    r times (default 4) (host/dac_sequence.py averages and plots them)
      Enter or W -> type new inputs: it asks for each value, then prints the decision
      I 15 35 50 20 100 300 0.5 -> all seven inputs on one line (temperature, salinity, depth,
                    turbidity, battery, range, speed); the report ends with a DECISION line
                    for programs (host/demo.py)
      R 450      -> set target range to 450 m
      M geo      -> modulation: auto | lfm | geo | bpsk | cw
      P          -> inputs from the potentiometers <-> typed inputs
      L          -> live status line on/off
      ?          -> help
  ============================================================================
*/
#include <Arduino.h>
#include <SPI.h>
#include "sonar_config.h"
#include "sonar_core.h"
#include "water_sim.h"
#if __has_include("esp_adc/adc_continuous.h")
#include "esp_adc/adc_continuous.h"
#include "esp_adc/adc_cali_scheme.h"
#include "esp_timer.h"
#define HAVE_ADC_CAPTURE 1
#else
#define HAVE_ADC_CAPTURE 0
#endif

// 1 = the ML model picks the profile, its amplitude and the modulation (ml_model.h, see ml/); the
//     physics keeps the profile when it closes the link within the energy allowance and overrides
//     it otherwise (FLAG_ML_USED / FLAG_ML_OVERRIDDEN), raises the amplitude if it is too low, and
//     replaces a modulation that cannot take the motion (FLAG_ML_MOD_OVERRIDDEN)
// 0 = physics only
#ifndef USE_ML_MODEL
#define USE_ML_MODEL 1
#endif

/* ------------------------------------------------------------ board pins */
// Pots on ADC1 pins (ADC2 is unusable when WiFi is on, so we stay on ADC1).
// Avoid GPIO 26-37 (flash/PSRAM on N16R8), 19/20 (USB), 0/3/45/46 (strapping).
#define PIN_POT_TEMP        1
#define PIN_POT_SALINITY    2
#define PIN_POT_DEPTH       3
#define PIN_POT_TURBIDITY   4
#define PIN_POT_BATTERY     5

// SPI to the FPGA (Tang Nano pins in brackets). The SPI signals go through the GPIO matrix,
// so any GPIO works; 2 MHz is far below its limit.
#define PIN_FPGA_CS         14    // -> FPGA pin 36
#define PIN_FPGA_MOSI       12    // -> FPGA pin 37
#define PIN_FPGA_SCK        13    // -> FPGA pin 38
#define PIN_FPGA_MISO       11    // -> FPGA pin 39 (not driven by the FPGA; unused)
#define FPGA_SPI_HZ         2000000UL     // [ASSUMPTION] confirm with FPGA owner
#define FPGA_SPI_MODE       SPI_MODE0     // [ASSUMPTION] confirm with FPGA owner

#define POT_FULLSCALE_MV    3100          // ESP32-S3 ADC @11 dB tops out near 3.1 V
#define ADC_OVERSAMPLE      16

/* ------------------------------------------------------------- RTOS setup */
#define SENSOR_PERIOD_MS    20            // 50 Hz sensor sampling
// decisions: PING_RATE_HZ (sonar_config.h), one per ping
#define SPI_PERIOD_MS       20            // 50 Hz packet refresh to FPGA (a new decision reaches it fast)
#define LOG_PERIOD_MS       500
#define SENSOR_STALE_MS     500           // decision refuses data older than this
#define SENSOR_FILTER_ALPHA 0.2f          // EMA smoothing of pot noise

// priorities (higher = more urgent): SPI > decision > sensor > console
#define PRIO_SPI            4
#define PRIO_DECISION       3
#define PRIO_SENSOR         2
#define PRIO_CONSOLE        1
#define CORE_A              0             // SPI + console
#define CORE_B              1             // sensor + decision

/* ----------------------------------------------------------- shared data */
// version: bumped by every typed change, so the decision starts fresh and the console can wait for it
struct SensorSample { sonar::Env env; uint32_t stampMs; uint32_t version; };
struct MlPick       { int profile; float amp; int mod; };   // the ML's own picks (-1 = none)
struct Telemetry    { sonar::Env env; sonar::Decision dec; sonar::SonarPacket pkt; uint32_t rangeM;
                      uint32_t staleCount; int32_t forcedMod; uint32_t version; MlPick ml;
                      int contact; float missionS; };           // contact: the simulator's, -1 = none

static QueueHandle_t qSensor = NULL;   // length 1, always holds the LATEST sample
static QueueHandle_t qPacket = NULL;   // length 1, always holds the LATEST packet
static QueueHandle_t qTelem  = NULL;   // length 1, latest telemetry for the console
static QueueHandle_t qPing   = NULL;   // every decision, for the PING log

static volatile uint32_t gTargetRangeM = DEFAULT_TARGET_RANGE_M;  // aligned 32-bit write is atomic
static volatile int32_t  gModulation   = -1;   // M command: -1 = auto (from the motion), else Modulation
static volatile bool     gSim          = true;   // A command: simulated water conditions (water_sim.h)
static volatile bool     gCapture      = false;  // C command running: the decision task leaves the packet alone
static volatile bool     gUsePots      = false;  // P command: potentiometers, else typed inputs
static volatile bool     gLive         = false;  // L command: status line every LOG_PERIOD_MS

// The typed inputs (the speed is typed in both modes: there is no sensor for it yet)
static portMUX_TYPE      gInputLock    = portMUX_INITIALIZER_UNLOCKED;
static sonar::Env        gTyped        = { 15.0f, 35.0f, 50.0f, 20.0f, 100.0f, DEFAULT_SPEED_MS };
static uint32_t          gInputVersion = 0;

static const char *const MOD_NAMES[] = { "cw", "lfm", "geo", "bpsk" };
static SPIClass spiFpga(FSPI);

#if USE_ML_MODEL
#include "ml_model.h"
// The ML model's choice (two small neural networks trained by ml/train.py on the physics'
// own decisions): the profile, and the amplitude for that profile. It always answers;
// sonar::decide() checks it with the physics.
static MlPick mlSelect(const sonar::Env &env, uint32_t rangeM) {
  sonar::Env e = env;
  sonar::sanitizeEnv(e);                              // the ranges the model was trained on
  const float r = sonar::clampf((float)rangeM, (float)MIN_TARGET_RANGE_M, (float)MAX_TARGET_RANGE_M);
  const float in[ml::ML_IN] = { e.tempC, e.salinityPpt, e.depthM, e.turbidityNtu, e.batteryPct, r };
  const int k = ml::ml_predict_profile(in);
  return { k, ml::ml_predict_amplitude(in, k), -1 };
}
// The modulation for the profile the physics settled on
static int mlModulation(const sonar::Env &env, int profile) {
  sonar::Env e = env;
  sonar::sanitizeEnv(e);
  const float in[4] = { e.tempC, e.salinityPpt, e.depthM, e.speedMs };
  return ml::ml_predict_modulation(in, profile);
}
#endif

/* ------------------------------------------------------------- utilities */
static float readPotFraction(int pin) {
  uint32_t acc = 0;
  for (int i = 0; i < ADC_OVERSAMPLE; i++) acc += analogReadMilliVolts(pin);
  const float mv = (float)acc / ADC_OVERSAMPLE;
  return sonar::clampf(mv / (float)POT_FULLSCALE_MV, 0.0f, 1.0f);
}
static float scaleToRange(float lo, float hi, float t) { return lo + t * (hi - lo); }

/* ================================================================ TASKS */

// 1) SENSOR TASK: fixed-rate ADC read + smoothing (or the typed inputs) -> latest sample queue.
static void sensorTask(void *) {
  sonar::Env f = {};
  bool first = true;
  TickType_t last = xTaskGetTickCount();
  for (;;) {
    portENTER_CRITICAL(&gInputLock);
    const sonar::Env typed = gTyped;
    const uint32_t version = gInputVersion;
    portEXIT_CRITICAL(&gInputLock);
    if (!gUsePots) {
      f = typed;                              // exact, no smoothing
      first = true;
      const SensorSample s = { f, millis(), version };
      xQueueOverwrite(qSensor, &s);
      vTaskDelayUntil(&last, pdMS_TO_TICKS(SENSOR_PERIOD_MS));
      continue;
    }
    sonar::Env raw;
    raw.tempC        = scaleToRange(TEMP_MIN_C,      TEMP_MAX_C,      readPotFraction(PIN_POT_TEMP));
    raw.salinityPpt  = scaleToRange(SALINITY_MIN_PPT, SALINITY_MAX_PPT, readPotFraction(PIN_POT_SALINITY));
    raw.depthM       = scaleToRange(DEPTH_MIN_M,     DEPTH_MAX_M,     readPotFraction(PIN_POT_DEPTH));
    raw.turbidityNtu = scaleToRange(TURBIDITY_MIN_NTU, TURBIDITY_MAX_NTU, readPotFraction(PIN_POT_TURBIDITY));
    raw.batteryPct   = scaleToRange(BATTERY_MIN_PCT, BATTERY_MAX_PCT, readPotFraction(PIN_POT_BATTERY));
    raw.speedMs      = typed.speedMs;

    if (first) { f = raw; first = false; }
    else {
      const float a = SENSOR_FILTER_ALPHA;
      f.tempC        += a * (raw.tempC        - f.tempC);
      f.salinityPpt  += a * (raw.salinityPpt  - f.salinityPpt);
      f.depthM       += a * (raw.depthM       - f.depthM);
      f.turbidityNtu += a * (raw.turbidityNtu - f.turbidityNtu);
      f.batteryPct   += a * (raw.batteryPct   - f.batteryPct);
      f.speedMs       = raw.speedMs;
    }
    const SensorSample s = { f, millis(), version };
    xQueueOverwrite(qSensor, &s);
    vTaskDelayUntil(&last, pdMS_TO_TICKS(SENSOR_PERIOD_MS));
  }
}

// 2) DECISION TASK: physics + ML -> profile, amplitude, modulation -> packet.
//    Never touches SPI or Serial.
static void decisionTask(void *) {
  int prev[4] = { -1, -1, -1, -1 };    // anti flip-flop memory per target: the simulator's 3 contacts, or 1
  uint32_t lastVersion = 0;
  uint16_t seq = 0;
  uint32_t stale = 0;
  watersim::Sim sim;
  watersim::init(sim);
  const TickType_t t0 = xTaskGetTickCount();
  for (uint32_t k = 1;; k++) {
    sonar::Env env;
    uint32_t r = 0, version = 0;
    int who = -1;
    float missionS = 0.0f;
    bool fresh = false;
    if (gSim) {
      const watersim::Reading w = watersim::step(sim, 1.0f / PING_RATE_HZ);
      env = { w.tempC, w.salinityPpt, w.depthM, w.turbidityNtu, w.batteryPct, w.speedMs };
      r = (uint32_t)lroundf(w.rangeM);
      who = w.contact;
      missionS = w.missionS;
      version = gInputVersion;
      fresh = true;
    } else {
      SensorSample s;
      if (xQueuePeek(qSensor, &s, 0) == pdTRUE && (millis() - s.stampMs) <= SENSOR_STALE_MS) {
        env = s.env;
        r = gTargetRangeM;
        version = s.version;
        fresh = true;
      }
    }
    if (fresh) {
      if (version != lastVersion) {                       // new inputs: fresh start
        for (int &p : prev) p = -1;
        lastVersion = version;
      }
      int &last = prev[who >= 0 ? who : 3];
      MlPick ml = { -1, -1.0f, -1 };
#if USE_ML_MODEL
      ml = mlSelect(env, r);
#endif
      sonar::Decision d = sonar::decide(env, (float)r, last, ml.profile, ml.amp);
#if USE_ML_MODEL
      ml.mod = mlModulation(env, d.profile);
#endif
      sonar::chooseModulation(d, env, ml.mod);
      last = d.profile;
      const int32_t forced = gModulation;
      const sonar::SonarPacket pkt = sonar::buildPacket(d, seq, forced);
      if (!gCapture) xQueueOverwrite(qPacket, &pkt);
      const Telemetry t = { env, d, pkt, r, stale, forced, version, ml, who, missionS };
      xQueueOverwrite(qTelem, &t);
      xQueueSend(qPing, &t, 0);
      seq++;
    } else {
      stale++;                       // no fresh data: keep the last good packet going
    }
    // PING_RATE_HZ exactly on average (1000 / 6 ms is not a whole number of ticks)
    const TickType_t next = t0 + pdMS_TO_TICKS((uint64_t)k * 1000u / PING_RATE_HZ);
    const TickType_t now = xTaskGetTickCount();
    if ((int32_t)(next - now) > 0) vTaskDelay(next - now);
  }
}

// 3) SPI TASK: highest priority, fixed period, only job is to push the latest packet.
static void spiTask(void *) {
  TickType_t last = xTaskGetTickCount();
  for (;;) {
    sonar::SonarPacket pkt;
    if (xQueuePeek(qPacket, &pkt, 0) == pdTRUE) {
      spiFpga.beginTransaction(SPISettings(FPGA_SPI_HZ, MSBFIRST, FPGA_SPI_MODE));  // set the mode first,
      digitalWrite(PIN_FPGA_CS, LOW);                                                // then select the FPGA
      spiFpga.writeBytes((const uint8_t *)&pkt, sizeof(pkt));
      digitalWrite(PIN_FPGA_CS, HIGH);
      spiFpga.endTransaction();
    }
    vTaskDelayUntil(&last, pdMS_TO_TICKS(SPI_PERIOD_MS));
  }
}

// 4) CONSOLE TASK: lowest priority. Serial commands, the typed-input prompts, the decision report
//    and the optional live status line.

// Console output in small pieces, each sent before the next is queued: the USB-Serial/JTAG driver
// loses text when it is queued faster than the host collects it, and Serial.flush() can discard it
static void out(const char *fmt, ...) {
  static int emptyRoom = 0;                 // free space of the empty transmit buffer
  char buf[320];
  va_list a;
  va_start(a, fmt);
  const int n = vsnprintf(buf, sizeof buf, fmt, a);
  va_end(a);
  for (int i = 0; i < n && i < (int)sizeof buf - 1; i += 32) {
    Serial.write((const uint8_t *)buf + i, (n - i < 32) ? n - i : 32);
    for (int w = 0; w < 20; w++) {
      const int room = Serial.availableForWrite();
      if (room > emptyRoom) emptyRoom = room;
      if (room >= emptyRoom) break;
      vTaskDelay(1);
    }
    vTaskDelay(1);                          // the host picks it up from the chip
  }
}

// The values the W command asks for, in order
struct Field { const char *name; const char *unit; float lo, hi; };
static const Field FIELDS[] = {
  { "Temperature",    "C",   TEMP_MIN_C,                TEMP_MAX_C },
  { "Salinity",       "ppt", SALINITY_MIN_PPT,          SALINITY_MAX_PPT },
  { "Depth",          "m",   DEPTH_MIN_M,               DEPTH_MAX_M },
  { "Turbidity",      "NTU", TURBIDITY_MIN_NTU,         TURBIDITY_MAX_NTU },
  { "Battery",        "%",   BATTERY_MIN_PCT,           BATTERY_MAX_PCT },
  { "Target range",   "m",   (float)MIN_TARGET_RANGE_M, (float)MAX_TARGET_RANGE_M },
  { "Relative speed", "m/s", SPEED_MIN_MS,              SPEED_MAX_MS },
};
static const int NUM_FIELDS = (int)(sizeof(FIELDS) / sizeof(FIELDS[0]));

static float    gDraft[NUM_FIELDS];
static int      gAsk = -1;               // the field being asked for, -1 = not asking
static uint32_t gWaitVersion = 0;        // print the report of the decision with this input version
static uint32_t gWaitStartMs = 0;
static bool     gWaiting = false;
static bool     gMachine = false;        // the I command: end the report with a DECISION line

static void printPrompt() {
  if (!gSim) out("\nEnter = new inputs, ? = help > ");
}

static void printHelp() {
  out("\n  A            automatic: simulated water conditions, one PING line per ping\n");
  out("  C [amp]      DAC view: record GPIO 1 during a slow-motion copy of the current ping\n");
  out("  S [n] [r]    DAC view of the next n pings (default 6), each recorded r times (default 4)\n");
  out("  Enter or W   type new inputs (Enter keeps a value, q cancels)\n");
  out("  R <metres>   target range, e.g. R 450\n");
  out("  M <mod>      modulation: auto (from the motion) | lfm | geo | bpsk | cw\n");
  out("  P            inputs from the potentiometers <-> typed inputs\n");
  out("  L            live status line on/off\n");
}

// Apply a change and wait for the decision that uses it
static void inputsChanged() {
  portENTER_CRITICAL(&gInputLock);
  gWaitVersion = ++gInputVersion;
  portEXIT_CRITICAL(&gInputLock);
  gWaiting = true;
  gWaitStartMs = millis();
}

static void askField() {
  const Field &f = FIELDS[gAsk];
  out("%s (%g..%g %s) [%g]: ", f.name, f.lo, f.hi, f.unit, gDraft[gAsk]);
}

static void startAsking() {
  portENTER_CRITICAL(&gInputLock);
  const sonar::Env e = gTyped;
  portEXIT_CRITICAL(&gInputLock);
  const float now[NUM_FIELDS] = { e.tempC, e.salinityPpt, e.depthM, e.turbidityNtu, e.batteryPct,
                                  (float)gTargetRangeM, e.speedMs };
  memcpy(gDraft, now, sizeof(gDraft));
  out("%s\n", gUsePots ? "\nPotentiometers are on (P): only the range and the speed are used from here."
                          : "\nNew inputs (Enter keeps the value in brackets, q cancels):");
  gAsk = 0;
  askField();
}

static void finishAsking() {
  gAsk = -1;
  gSim = false;
  gMachine = false;
  portENTER_CRITICAL(&gInputLock);
  gTyped.tempC        = gDraft[0];
  gTyped.salinityPpt  = gDraft[1];
  gTyped.depthM       = gDraft[2];
  gTyped.turbidityNtu = gDraft[3];
  gTyped.batteryPct   = gDraft[4];
  gTyped.speedMs      = gDraft[6];
  gTargetRangeM       = (uint32_t)lroundf(gDraft[5]);
  portEXIT_CRITICAL(&gInputLock);
  inputsChanged();
}

static void answerField(const char *w) {
  if (*w == 'q' || *w == 'Q') { gAsk = -1; out("cancelled\n"); printPrompt(); return; }
  if (*w) {
    char *end;
    const float v = strtof(w, &end);
    const Field &f = FIELDS[gAsk];
    if (end == w || *end || !(v >= f.lo && v <= f.hi)) {
      out("  \"%s\": must be a number from %g to %g\n", w, f.lo, f.hi);
      askField();
      return;
    }
    gDraft[gAsk] = v;
  }
  if (++gAsk < NUM_FIELDS) askField();
  else finishAsking();
}

// DAC view (C command): records the DAC filter's output on GPIO 1 with the ESP32's ADC. The ADC
// (80 kS/s at most) is far too slow for 100-500 kHz, so the FPGA is sent a slow-motion copy of the
// current waveform: every frequency divided by N and the pulse N times longer (N up to 100), which it
// plays through the real sigma-delta and filter. host/dac_view.py plots it against the FPGA's samples.
#define DAC_VIEW_ADC_CHANNEL  0          // GPIO 1 = ADC1 channel 0
#define DAC_VIEW_MAX_SAMPLES  50000
#define DAC_VIEW_MAX_RATE     80000

static bool slowPacket(const Telemetry &t, float amp, sonar::SonarPacket &k, int &n) {
  WaveProfile p = sonar::withModulation(PROFILES[t.dec.profile], t.pkt.modulation);
  n = (int)fmin(100.0, floor((double)FPGA_LEN_MAX_CLK / (p.pulseS * FPGA_CLK_HZ * 1.02)));
  if (n < 2) return false;
  p.fcHz /= n;
  p.bwHz /= n;
  p.pulseS *= n;
  const sonar::FpgaWave w = sonar::fpgaWave(p);
  if (!w.fits) return false;
  k = t.pkt;
  k.lenClk    = w.lenClk;
  k.ftwStart  = w.ftwStart;
  k.ftwStep   = w.ftwStep;
  k.winStep   = w.winStep;
  k.code      = w.code;
  k.chipLen   = w.chipLen;
  k.periodClk = w.lenClk + w.lenClk / 2;
  if (amp > 0.0f) k.ampQ12 = (uint16_t)lroundf(sonar::clampf(amp, 0.0f, 1.0f) * 4096.0f);
  k.crc8      = sonar::crc8((const uint8_t *)&k, sizeof(k) - 1);
  return true;
}
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
void loop() {
  vTaskDelay(pdMS_TO_TICKS(1000));   // all work happens in the RTOS tasks
}

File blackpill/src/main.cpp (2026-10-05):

/*
 * Real-speed recorder for the sonar DAC: the BlackPill's ADC samples the filtered DAC output at
 * 2.4 MS/s, so the real 100-500 kHz pulse can be seen on the laptop without slowing it down
 * (host/real_speed.py plots it against the FPGA's own samples).
 *
 * Wiring:
 *   PA1  <- the OPA340's output (LASC board J6 pin 7, channel 2 / U3); P 0 switches to PA0 (J6 pin 6)
 *   PB0  <- FPGA pin 41 (high for as long as each pulse lasts)
 *   GND  <- FPGA GND
 *
 * The ADC runs continuously into a circular buffer through DMA. A rising edge on PB0 marks where
 * the pulse starts; the recording keeps `pre` samples from before it and stops after the rest.
 *
 * Commands over USB (one per line):
 *   C [n] [pre]          the next pulse: n samples (default 4800 = 2 ms), pre of them before it
 *   S [k] [n] [pre]      the next k consecutive pulses (default 6), each sent as soon as it is in
 *   P <0|1>              record PA0 or PA1
 *   T <0..7>             ADC sampling time: 3, 15, 28, 56, 84, 112, 144, 480 ADC clocks (default 0 = 3,
 *                        2.4 MS/s; longer is slower but gives the input more time to settle)
 *   ?                    status
 * Each recording is a text line "CAP i=.. n=.. pre=.. rate=.. ch=.. t_us=..", then n
 * little-endian 16-bit samples (12-bit ADC counts), then "\nEND\n". A sequence ends with "SEQEND".
 */
#include <Arduino.h>

#define BUF_N     40000u                // 80 KB of RAM: 16.6 ms at 2.4 MS/s
#define TRIG_PIN  PB0

static uint16_t buf[BUF_N] __attribute__((aligned(4)));
static volatile int32_t trigAt = -1;    // buffer index at the trigger, -1 = not yet
static volatile bool armed = false;
static uint8_t channel = 1;
static uint8_t smp = 0;                 // sampling time code, see the T command
static float rate = 0;                  // measured samples per second

// 72 MHz from the 25 MHz crystal (USB still gets its 48 MHz); APB2 = 72 MHz, ADC = APB2 / 2 = 36 MHz
extern "C" void SystemClock_Config(void) {
  RCC_OscInitTypeDef osc = {};
  RCC_ClkInitTypeDef clk = {};
  __HAL_RCC_PWR_CLK_ENABLE();
  __HAL_PWR_VOLTAGESCALING_CONFIG(PWR_REGULATOR_VOLTAGE_SCALE1);
  osc.OscillatorType = RCC_OSCILLATORTYPE_HSE;
  osc.HSEState = RCC_HSE_ON;
  osc.PLL.PLLState = RCC_PLL_ON;
  osc.PLL.PLLSource = RCC_PLLSOURCE_HSE;
  osc.PLL.PLLM = 25;
  osc.PLL.PLLN = 144;
  osc.PLL.PLLP = RCC_PLLP_DIV2;
  osc.PLL.PLLQ = 3;
  if (HAL_RCC_OscConfig(&osc) != HAL_OK) Error_Handler();
  clk.ClockType = RCC_CLOCKTYPE_HCLK | RCC_CLOCKTYPE_SYSCLK | RCC_CLOCKTYPE_PCLK1 | RCC_CLOCKTYPE_PCLK2;
  clk.SYSCLKSource = RCC_SYSCLKSOURCE_PLLCLK;
  clk.AHBCLKDivider = RCC_SYSCLK_DIV1;
  clk.APB1CLKDivider = RCC_HCLK_DIV2;
  clk.APB2CLKDivider = RCC_HCLK_DIV1;
  if (HAL_RCC_ClockConfig(&clk, FLASH_LATENCY_2) != HAL_OK) Error_Handler();
}

static inline uint32_t writePos() { return BUF_N - DMA2_Stream0->NDTR; }

static void adcStop() {
  ADC1->CR2 &= ~(ADC_CR2_ADON | ADC_CR2_CONT | ADC_CR2_DMA);
  DMA2_Stream0->CR &= ~DMA_SxCR_EN;
  while (DMA2_Stream0->CR & DMA_SxCR_EN) {}
}

static void setSampling(uint8_t code) {
  smp = code & 7;
  uint32_t r = 0;
  for (int ch = 0; ch < 10; ch++) r |= (uint32_t)smp << (3 * ch);
  ADC1->SMPR2 = r;
}

static void adcInit() {
  RCC->APB2ENR |= RCC_APB2ENR_ADC1EN;
  RCC->AHB1ENR |= RCC_AHB1ENR_DMA2EN | RCC_AHB1ENR_GPIOAEN;
  GPIOA->MODER |= (3u << 0) | (3u << 2);                  // PA0, PA1 analog
  ADC->CCR = ADC->CCR & ~ADC_CCR_ADCPRE;                   // ADC clock = PCLK2 / 2
  ADC1->CR1 = 0;                                           // 12 bits
  setSampling(0);                                          // 3-cycle sampling: 15 clocks a sample
  ADC1->SQR1 = 0;                                          // one channel
}

// ADC1 -> DMA2 stream 0 (channel 0), circular over the whole buffer
static void adcStart() {
  adcStop();
  DMA2->LIFCR = 0x3D;                                      // clear stream 0's flags
  DMA2_Stream0->PAR = (uint32_t)&ADC1->DR;
  DMA2_Stream0->M0AR = (uint32_t)buf;
  DMA2_Stream0->NDTR = BUF_N;
  DMA2_Stream0->FCR = 0;
  DMA2_Stream0->CR = DMA_SxCR_PL | DMA_SxCR_MSIZE_0 | DMA_SxCR_PSIZE_0 | DMA_SxCR_MINC | DMA_SxCR_CIRC;
  DMA2_Stream0->CR |= DMA_SxCR_EN;
  ADC1->SR = 0;
  ADC1->SQR3 = channel;
  ADC1->CR2 = ADC_CR2_ADON | ADC_CR2_CONT | ADC_CR2_DMA | ADC_CR2_DDS;
  delayMicroseconds(5);                                    // the ADC's start-up time
  ADC1->CR2 |= ADC_CR2_SWSTART;
}

static void measureRate() {
  CoreDebug->DEMCR |= CoreDebug_DEMCR_TRCENA_Msk;
  DWT->CTRL |= DWT_CTRL_CYCCNTENA_Msk;
  adcStart();
  delay(2);
  const uint32_t c0 = DWT->CYCCNT, p0 = writePos();
  while (DWT->CYCCNT - c0 < SystemCoreClock / 100) {}     // 10 ms, fewer samples than the buffer
  const uint32_t c1 = DWT->CYCCNT, p1 = writePos();
  adcStop();
  rate = (float)((p1 + BUF_N - p0) % BUF_N) * SystemCoreClock / (c1 - c0);
}

static void onTrigger() {
  if (armed) {
    trigAt = writePos();
    armed = false;
  }
}

// Wait for the next pulse and record around it. false if none comes within timeoutMs.
static bool record(uint32_t n, uint32_t pre, uint32_t timeoutMs, uint32_t &tUs) {
  adcStart();
  delayMicroseconds((uint32_t)((uint64_t)pre * 1000000u / (uint32_t)rate) + 20);   // the samples before it
  trigAt = -1;
  armed = true;
  const uint32_t t0 = millis();
  while (trigAt < 0) {
    if (millis() - t0 > timeoutMs) {
      armed = false;
      adcStop();
      return false;
    }
  }
  tUs = micros();
  const uint32_t start = (uint32_t)trigAt, after = n - pre;
  while ((writePos() + BUF_N - start) % BUF_N < after) {}
  adcStop();
  return true;
}

static void send(uint32_t index, uint32_t n, uint32_t pre, uint32_t tUs) {
  Serial.printf("CAP i=%lu n=%lu pre=%lu rate=%lu ch=%u t_us=%lu\n", (unsigned long)index,
                (unsigned long)n, (unsigned long)pre, (unsigned long)lroundf(rate), channel, (unsigned long)tUs);
  const uint32_t first = ((uint32_t)trigAt + BUF_N - pre) % BUF_N;
  const uint32_t part = min(n, BUF_N - first);
  Serial.write((const uint8_t *)&buf[first], part * 2);
  if (part < n) Serial.write((const uint8_t *)buf, (n - part) * 2);
  Serial.print("\nEND\n");
}

static void clampSizes(uint32_t &n, uint32_t &pre) {
  if (n < 16) n = 4800;
  if (n > BUF_N - 2000) n = BUF_N - 2000;                   // room for the time it takes to stop
  if (pre >= n) pre = n / 10;
}
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

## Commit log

2026-09-28 Finished waveform generator demo: UART settings from the PC, capture + check
    Verified on the Tang Nano 9K: LFM chirp up/down, BPSK Barker-13/Barker-7 and a tone,
    each 16,383 captured samples bit-exact against the golden model.
2026-09-28 Finished reference: PC-controlled waveform generator, verified on the Tang Nano 9K
    Chirp (up/down), BPSK (Barker-13/7) and tone all match the golden model
    bit for bit on the board. Settings arrive over the USB UART as a 24-byte
    struct; the capture buffer sends a pulse back for checking.
2026-09-28 README: restore the Barker-7 example and the top_tb frames note
2026-09-29 Geometric sweep: shift-and-add multiplier in sweep.v, 26-byte struct with mode
    sweep.v gets a geo input: every 32 clocks ftw grows by ftw * step / 2^32, worked out
    one bit of step per clock, so no 32x32 multiplier is needed. The settings struct gains
    a mode field (bit 0 = geometric), S1 cycles chirp -> geo -> BPSK, LED 5 shows geo.
    wavegen.py adds `geo` and drops --code (always Barker-13), --down and --len
    (fixed at 13000 clocks, 1000 per chip). New geo_tb + check_geo.py; top_tb sends
    chirp, geo and BPSK. sim/all 9/9 pass; all waveforms bit-exact on the board.
    [capture.py, check_geo.py, model.py]
2026-09-30 ESP32 link over SPI, packet v3, detail-vs-energy rule, ML waveform choice
    FPGA
    - spi_rx.v: SPI mode-0 receiver; frames by CS or (USE_CS=0, used on these boards) by the
    100 us pause after each burst, because the CS wire only carries noise.
    - pkt_check.v: sync, version and CRC-8 check of the 57-byte ESP32 packet.
    - Settings now come from that packet over SPI or inside a UART frame from the PC; 24-bit
    pulse length and chip length, 48-bit sweep register (LFM step in 1/65536 FTW), 32-bit
    period; capture header carries the settings and good/bad SPI packet counts.
    - host/mcu_packet.py mirrors the firmware's packet and unit conversion; wavegen.py sends real
    ESP32 packets; top_tb plays PC and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
    [test_vectors.csv]
2026-09-30 Oscilloscope outputs (sigma-delta 1-bit DAC + trigger), 2-clock scale multiply
    The single-clock LUT multiply in scale.v gave wrong products on the chip once the
    sigma-delta was added, though the timing report passed; it now registers two partial
    products. Golden model, testbench resets and docs updated; the build is in flash.
    [check_sigma_delta.py, model.py]
2026-09-30 Simulated water conditions, 6 pings/s, Doppler modulation choice, streamed captures, demo
    ESP32: water_sim.h drives the inputs by default (dive through a thermocline, three contacts
    pinged in turn); one decision per ping at 6 Hz; a relative-speed input and the Doppler rule
    pick BPSK / LFM / geometric, proposed by a third network (16-32-32-3) and checked by the
    physics; serial console with typed inputs, PING and DECISION lines; paced USB output.
    FPGA: UART at 3 Mbaud; capture keeps one sample in 2^shift so whole pulses fit; stream mode
    (A5 03 03 / A5 04 04); header carries the packet's seq, profile and flags and the pulse number.
    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
    [test_vectors_mod.csv]
2026-10-04 DAC view without a scope: ESP32 ADC records the sigma-delta output in slow motion
    ESP32 command C [amp] sends the FPGA a slow-motion copy of the current ping (frequencies / N,
    pulse x N), records the filtered sigma-delta output on GPIO 1 with the continuous ADC and prints
    it; host/dac_view.py plots it over the golden model's samples for the same packet. Verified:
    correlation 0.998 at full amplitude, BPSK phase flips visible. golden() can keep every Nth tick.
    [adaptive_sonar.ino, dac_view.py, model.py]
2026-10-04 DAC view of one second of pings: ESP32 S command + host/dac_sequence.py
    The ESP32 takes its next 6 decisions and records each one 4 times in slow motion through the
    sigma-delta DAC and filter; dac_sequence.py lines every recording up with the golden model,
    averages them and draws the six on one broken-time-axis graph with close-ups and a table of the
    conditions. Verified on the boards: correlation 0.92-0.999 per ping (0.92 at amplitude 0.05).
    [adaptive_sonar.ino, dac_sequence.py]
2026-10-04 dac_sequence.py: shorter labels, colour key across the top
    [dac_sequence.py]
2026-10-04 BlackPill real-speed recorder (2.4 MS/s ADC) and host/real_speed.py
2026-10-04 Docs: BlackPill real-speed recorder and the Sallen-Key filter
2026-10-04 Second-order sigma-delta DAC (default), finer real-speed alignment
    sigma_delta.v: ORDER parameter, 2 by default (two integrators, input limited to
    +-95%); the testbench and checker verify both orders bit-exact. Measured with the
    BlackPill on fixed pings: leftover noise 28->22, 16->13, 17->12.5 mV rms.
    real_speed.py: rate search to 0.0005%, which the 2.4 MS/s recordings need.
    [check_sigma_delta.py, dac_view.py, real_speed.py]
2026-10-05 BlackPill: T command sets the ADC sampling time
    Measured with it: the height loss at 300-440 kHz (0.95, 0.86) does not change with
    a 5x longer sampling time, so it is in the analog path, not the ADC.
2026-10-05 host/energy_compare.py: adaptive vs fixed sonar energy over a full battery cycle
    [energy_compare.py]
2026-10-05 Add the output filter's KiCad schematic and an ngspice AC sweep
    [Sallen-Key.kicad_pcb, Sallen-Key.kicad_sch]
